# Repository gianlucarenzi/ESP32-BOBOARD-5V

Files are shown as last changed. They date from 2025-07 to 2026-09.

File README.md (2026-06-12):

# ESP32-BOBOARD-5V

**ESP32 NodeMCU 5V Tolerant Breakout Board per Monitoraggio Bus 6502**

## 🌐 Language / Lingua




---

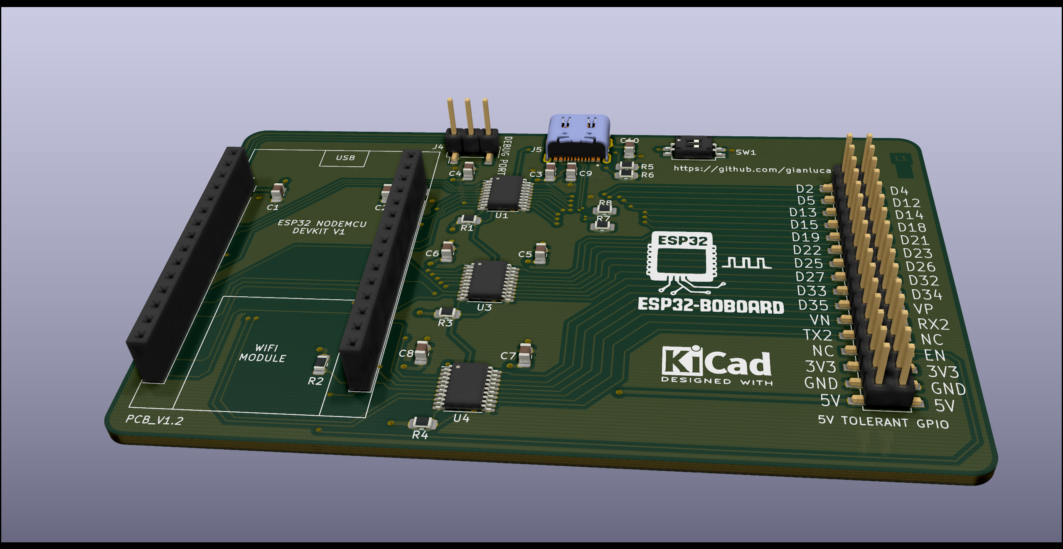
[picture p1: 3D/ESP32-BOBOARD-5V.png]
ESP32-BOBOARD-5V


## 📋 Indice

- [Panoramica del Progetto](#panoramica-del-progetto)
- [Caratteristiche Principali](#caratteristiche-principali)
- [Specifiche Tecniche](#specifiche-tecniche)
- [Visualizzazione 3D](#visualizzazione-3d)
- [Architettura Hardware](#architettura-hardware)
- [Firmware](#firmware)
- [Installazione e Setup](#installazione-e-setup)
- [Utilizzo](#utilizzo)
- [Diagrammi di Flusso](#diagrammi-di-flusso)
- [Tempistiche](#tempistiche)
- [File del Progetto](#file-del-progetto)
- [Produzione](#produzione)
- [Licenza](#licenza)
- [Contributi](#contributi)

## 🎯 Panoramica del Progetto

ESP32-BOBOARD-5V è una scheda breakout specializzata progettata per interfacciare un modulo ESP32 NodeMCU con sistemi basati su processore 6502, come l'Atari 8-bit. La scheda fornisce:

- **Tolleranza 5V** per tutti i pin GPIO
- **Monitoraggio del bus 6502** in tempo reale
- **Implementazione PBI (Parallel Bus Interface)** per Atari
- **Level shifting bidirezionale** per compatibilità 3.3V/5V
- **Connettori standard** per facile integrazione

### 🎮 Applicazioni Principali

- Monitoraggio e debug di sistemi 6502
- Implementazione di periferiche PBI per Atari
- Analisi del traffico del bus dati/indirizzi
- Emulazione di ROM e RAM esterne
- Sviluppo di cartucce intelligenti

## ✨ Caratteristiche Principali

### Hardware
- **ESP32 NodeMCU** compatibile (240MHz dual-core)
- **3x TXS0108E** level shifters bidirezionali
- **Tolleranza 5V** su tutti i pin GPIO
- **Connettore USB-C** per programmazione e alimentazione
- **Connettore PBI** standard per Atari
- **Pin header** per accesso completo ai GPIO
- **LED di stato** e pulsanti di controllo

### Firmware
- **PBI ROM Emulator** ($D800–$DFFF, 2 KB — decode completo A0-A10, nessun aliasing)
- **Dual-core processing** (Core 0: Serial/Log, Core 1: Monitor bus)
- **MPD** asserted durante accessi ROMSEL
- **EXTSEL** asserted durante accessi $D1XX con latch attivo
- **Latch interno** controllato via scrittura a $D1FF ($80 = enable, $00 = disable)
- **Coda FreeRTOS** (Core 1 → Core 0): log cambi stato latch VCS e ogni accesso $D100–$D1FE con timestamp in microsecondi

## 🔧 Specifiche Tecniche

| Parametro | Valore |
|---|---|
| **Microcontrollore** | ESP32-WROOM-32 |
| **Frequenza CPU** | 240 MHz (dual-core) |
| **Memoria Flash** | 4MB |
| **RAM** | 520KB |
| **GPIO disponibili** | 30 pin |
| **Level Shifters** | 3x TXS0108E (8-bit bidirezionali) |
| **Alimentazione** | 5V via USB-C o pin |
| **Logica I/O** | 3.3V/5V tolerant |
| **Dimensioni PCB** | 21.7mm x 21.7mm |
| **Layers** | 4 layer PCB |

### Pinout 6502 Bus

| Segnale | Pin ESP32 | Descrizione |
|---|---|---|
| **D0-D7** | GPIO4, GPIO5, GPIO13, GPIO14, GPIO16, GPIO17, GPIO18, GPIO19 | Data Bus (Bidirezionale) |
| **A0-A3** | GPIO34, GPIO35, GPIO36, GPIO39 | Address Bus LSB (Input Only) |
| **A4-A7** | GPIO32, GPIO33, GPIO21, GPIO27 | Address Bus |
| **A8-A10** | GPIO12, GPIO25, GPIO26 | Address Bus (decode completo 2 KB) |
| **PHI2** | GPIO2 | Clock 6502 (1.79 MHz) |
| **R/W** | GPIO15 | Read/Write |
| **SEL_N** | GPIO22 | Selezione $D1XX / CCTL (Active Low, Input) |
| **ROMSEL** | GPIO23 | Range $D800–$DFFF (Active Low, Input) |
| **EXTSEL** | GPIO3 (RX0) | Disabilita memoria interna Atari (Active Low, Output) |
| **MPD** | GPIO0 (BOOT) | Math Pack Disable (Active Low, Output) |

## 🎨 Visualizzazione 3D

### 📱 Viewer Online Interattivi

Visualizza i modelli 3D direttamente nel browser:







### 📥 Download File 3D

| Formato | Descrizione | Download |
|---|---|---|
| **STEP** | Modello CAD parametrico |  |
| **WRL** | Modello VRML per rendering |  |

### 🖼️ Galleria Immagini 3D

<table>
  <tr>
    <td align="center">
      Vista Isometrica
      <br/><b>Vista Isometrica</b>
    </td>
    <td align="center">
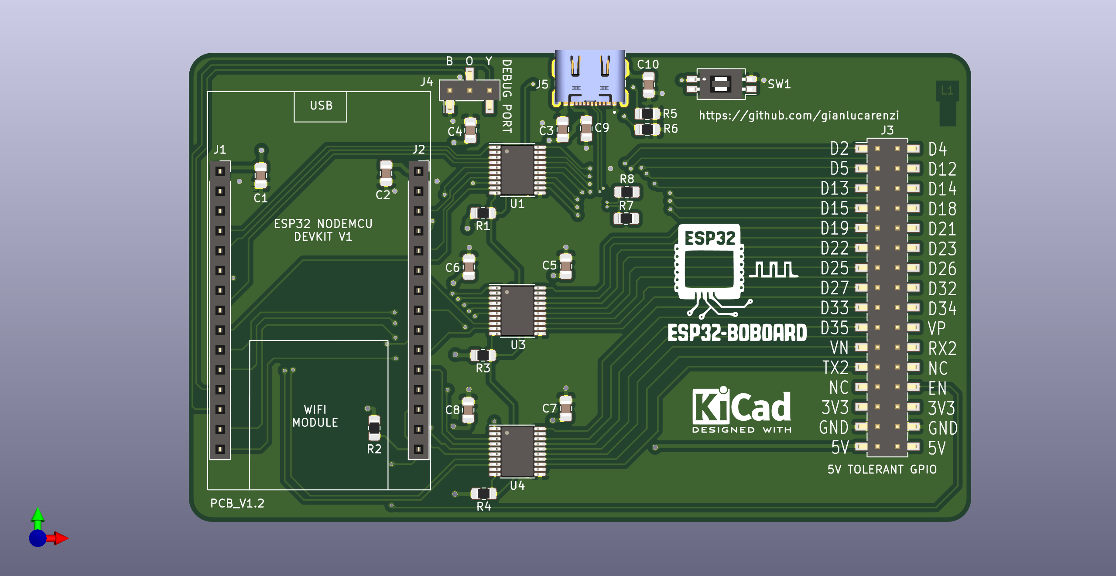
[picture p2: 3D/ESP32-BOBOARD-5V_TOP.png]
Vista Superiore
      
      <br/><b>Vista Superiore</b>
    </td>
  </tr>
  <tr>
    <td align="center">
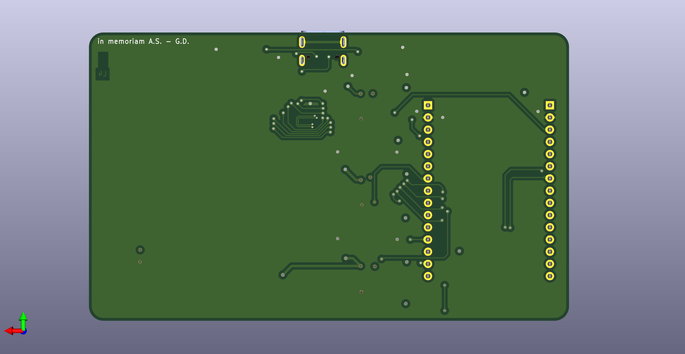
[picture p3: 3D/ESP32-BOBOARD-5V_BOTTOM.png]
Vista Inferiore
      
      <br/><b>Vista Inferiore</b>
    </td>
    <td align="center">
      Schema Elettrico
      <br/><b><a href="schematics/ESP32-BOBOARD-5V.pdf">📄 Schema Elettrico</a></b>
    </td>
  </tr>
</table>

### 🛠️ Software Consigliati per Visualizzazione

| Software | Formato | Piattaforma | Gratuito |
|---|---|---|---|
| **FreeCAD** | STEP, WRL | Windows, Linux, macOS | ✅ |
| **Fusion 360** | STEP | Windows, macOS | ✅ (Personal) |
| **Blender** | WRL | Windows, Linux, macOS | ✅ |
| **MeshLab** | WRL | Windows, Linux, macOS | ✅ |
| **CAD Exchanger Viewer** | STEP, WRL | Browser | ✅ |
| **3D Viewer Online** | STEP, WRL | Browser | ✅ |
| **Autodesk Viewer** | STEP | Browser | ✅ |

---

## 🏗️ Architettura Hardware

### Schema a Blocchi

```mermaid
flowchart TD
    A[ESP32 NodeMCU] --> B[TXS0108E #1]
    A --> C[TXS0108E #2] 
    A --> D[TXS0108E #3]
    
    B --> E[Data Bus D0-D7]
    C --> F[Address Bus A0-A7]
    D --> G[Address A8-A10 + Controls]
    
    E --> H[6502 System]
    F --> H
    G --> H
    
    I[USB-C] --> A
    J[Pin Headers] --> A
    K[PBI Connector] --> H
    
    style A fill:#e1f5fe
    style H fill:#f3e5f5
    style I fill:#e8f5e8
```

### Level Shifting

La scheda utilizza tre TXS0108E per garantire la compatibilità tra i livelli logici 3.3V dell'ESP32 e i 5V del sistema 6502:

- **TXS0108E #1**: Data Bus D0-D7 (bidirezionale)
- **TXS0108E #2**: Address Bus A0-A7
- **TXS0108E #3**: Address Bus A8-A10 + segnali di controllo (PHI2, R/W, SEL\_N, ROMSEL, EXTSEL, MPD)

## 💻 Firmware

### Architettura Software

Il firmware è basato su FreeRTOS e utilizza entrambi i core dell'ESP32:

- **Core 0**: Gestione comunicazione seriale e debug
- **Core 1**: Monitoraggio bus 6502 ad alta velocità

### Funzionalità Principali

#### 1. Monitoraggio Bus 6502
```cpp
// Lettura ottimizzata del bus indirizzi
static inline uint16_t read_address_bus(void) {
    uint32_t gpio_low = read_gpio_low();
    uint32_t gpio_high = read_gpio_high();
    // Combinazione bit per ricostruire indirizzo 16-bit
    return address_reconstruction;
}
```

#### 2. Implementazione PBI

| Range Indirizzi | Funzione | Note |
|---|---|---|
| **$D100–$D11F** | Registri VERA (accesso via EXTSEL) | Solo con latch attivo |
| **$D1FF** | Latch control (W: $80=on, $00=off) | Solo PBI mode |
| **$D800–$DFFF** | PBI ROM 2 KB — driver VERA X16 | A0-A10 decodificati, nessun aliasing |

#### 3. Sorgenti 6502 (ROM)

| File | Descrizione |
|---|---|
| `6502/src/vera_pbi_handler.s` | Driver PBI ROM per scheda VERA X16. Intestazione standard Earl Rice ($D800–$D81C), handler CIO, vettori OPEN/CLOSE/GET/PUT/STATUS/SPECIAL, init VERA. |
| `6502/src/vera_common.inc` | Simboli condivisi: indirizzi registri VERA (`VERA_ADDR_L/M/H`, `VERA_DATA0/1`, `VERA_CTRL`, …), costanti PBI (`PBI_ADDR=$D100`, `PBI_LATCH=$D1FF`), layout schermo. |
| `6502/pbi-driver.ld` | Linker script: segmento `ROM` origin `$D800`, size `$0800` (2 KB). |
| `include/pbi-driver.h` | Array C `pbi_driver[]` generato automaticamente dal Makefile — non modificare a mano. |

### Modalità di Funzionamento

#### Modalità PBI (Default)
```ini
-D BUS_MODE=0  ; BUS_MODE_PBI
```
- Emulazione dispositivo PBI Atari
- ROMSEL ($D800–$DFFF): assert MPD, serve byte ROM su letture (A0-A10)
- SEL_N ($D1XX): assert EXTSEL quando latch attivo
- Latch VCS: abilitato da `$80` a $D1FF, disabilitato da `$00`

#### Modalità CCTL (Cartridge)
```ini
-D BUS_MODE=1  ; BUS_MODE_CCTL
```
- Modalità Cartridge Control semplificata
- Latch sempre attivo (EXTSEL sempre asserted su $D1XX)
- Non gestisce $D1FF come controllo latch

## 🚀 Installazione e Setup

### Requisiti Hardware
- ESP32 NodeMCU (38 pin)
- Cavo USB-C per programmazione
- Sistema 6502 target (es. Atari 130XE)
- Connessioni bus secondo pinout

### Requisiti Software
- [PlatformIO](https://platformio.org/) o Arduino IDE
- ESP32 Arduino Core v2.0.14
- Driver USB-C per il sistema operativo

### Compilazione Firmware

1. **Clone del repository**:
```bash
git clone https://github.com/gianlucarenzi/esp32-boboard-5v.git
cd ESP32-BOBOARD-5V/firmware/6502_monitor
```

2. **Configurazione PlatformIO**:
```ini
[env:nodemcu-32s]
platform = espressif32
board = nodemcu-32s
framework = arduino
monitor_speed = 115200
board_build.f_cpu = 240000000
upload_speed = 921600
```

3. **Compilazione e upload**:
```bash
pio run --target upload
pio device monitor
```

### Configurazione Hardware

1. **Connessione ESP32**: Inserire il modulo NodeMCU nei socket
2. **Alimentazione**: Collegare USB-C o alimentazione 5V
3. **Bus 6502**: Collegare secondo il pinout specificato
4. **Test**: Eseguire modalità test per verifica connessioni

## 📊 Utilizzo

### Avvio Sistema

1. **Power-on**: Alimentare la scheda
2. **Monitor seriale**: Aprire terminale a 115200 baud
3. **Inizializzazione**: Attendere messaggio di ready
4. **Connessione 6502**: Collegare al sistema target

### Output Seriale

Il firmware stampa su Core 0 ogni evento loggato da Core 1 via coda FreeRTOS.
Il formato è `[secondi.microsecondi]`:

```
[6502_monitor] PBI ROM Emulator booting...
[6502_monitor] Running.
[6502_monitor] VCS=OFF  Latch=DISABLED
[    0.012345] [VCS ] Latch ENABLED  ($80 written to $D1FF)
[    0.012346] [D100 - VERA_ADDR_L          ] R $00
[    0.012390] [D103 - VERA_DATA0           ] W $FF
[    1.234567] [D104 - VERA_DATA1           ] W $00
[    1.234600] [VCS ] Latch DISABLED ($00 written to $D1FF)
```

- `[VCS ]` — cambio di stato del latch: `ENABLED` / `DISABLED`
- `[D1xx - NOME_REGISTRO]` — accesso a registro VERA con nome simbolico: `R` = lettura, `W` = scrittura
- I registri $09–$0C sono muxati da DCSEL: il logger traccia ogni scrittura a `VERA_CTRL` ($D105, bit [2:1]) per risolvere il nome corretto
- Il timestamp è catturato in Core 1 al momento del ciclo di bus (`esp_timer_get_time()`)
- Gli eventi persi quando la coda è piena vengono scartati senza bloccare il bus handler

## 📈 Diagrammi di Flusso

### Flusso Principale del Monitor

```mermaid
flowchart TD
    A[Avvio Sistema] --> B[Init GPIO + Drive LUT]
    B --> C[Crea coda FreeRTOS]
    C --> D[Avvia MonitorTask su Core 1]
    D --> E[Core 0: loop drain coda e Serial.printf]
    D --> F[Core 1: attesa PHI2 rising edge]

    F --> G[Campiona GPIO.in / GPIO.in1]
    G --> H[Decode indirizzo A0-A10 e R/W]
    H --> I{ROMSEL attivo?}

    I -->|Sì D800-DFFF| J[Assert MPD]
    J --> K{R/W = Read?}
    K -->|Sì| L[bus_drive pbi_rom addr]
    K -->|No| M[nessuna azione dati]

    I -->|No| N{SEL_N attivo?}
    N -->|Sì D1XX| O{latch attivo?}
    O -->|Sì| P[Assert EXTSEL]
    O -->|No| Q[EXTSEL rilasciato]
    P --> R{offset = $FF e Write?}
    Q --> R
    R -->|Sì PBI latch| S[Aggiorna latch, log EVT_LATCH se cambia]
    R -->|No D100-D1FE| T[log EVT_REG con R/W e dato]
    N -->|No| U[EXTSEL rilasciato]

    L --> V[Attesa PHI2 falling edge]
    M --> V
    S --> V
    T --> V
    U --> V
    V --> W[bus_release]
    W --> F

    style A fill:#e1f5fe
    style E fill:#f3e5f5
    style F fill:#e8f5e8
```

### Protocollo Latch VCS (PBI Mode)

```mermaid
sequenceDiagram
    participant CPU as 6502 CPU
    participant ESP as ESP32 MonitorTask
    participant Q  as FreeRTOS Queue

    CPU->>ESP: Write $80 → $D1FF
    ESP->>ESP: latch_active = true
    ESP->>ESP: Assert EXTSEL (LOW)
    ESP->>Q: EVT_LATCH ENABLED (timestamp µs)

    loop Accessi VERA $D100-$D1FE
        CPU->>ESP: Read/Write $D1xx
        ESP->>Q: EVT_REG offset data R/W (timestamp µs)
    end

    CPU->>ESP: Write $00 → $D1FF
    ESP->>ESP: latch_active = false
    ESP->>ESP: Release EXTSEL (HIGH)
    ESP->>Q: EVT_LATCH DISABLED (timestamp µs)
```

## ⏱️ Tempistiche

### Timing Critici

| Operazione | Tempo | Note |
|---|---|---|
| **PHI2 Period** | 1.77 MHz (PAL) / 1.79 MHz (NTSC) | Clock Atari 6502 |
| **Address Setup** | <100ns | Prima del rising edge PHI2 |
| **Data Setup** | <200ns | Per operazioni di write |
| **Data Hold** | <100ns | Dopo falling edge PHI2 |
| **GPIO Read** | ~125ns | Lettura registri ESP32 |
| **Level Shift** | <10ns | Propagazione TXS0108E |

### Diagramma Temporale Bus 6502

```mermaid
gantt
    title Timing Diagram - 6502 Bus Cycle
    dateFormat X
    axisFormat %L
    
    section PHI2
    High Phase    :active, phi2h, 0, 500
    Low Phase     :phi2l, 500, 1000
    
    section Address Bus
    Address Valid :addr, 0, 900
    Address Hold  :addrh, 900, 1000
    
    section Data Bus (Read)
    Data Setup    :data, 100, 400
    Data Valid    :active, datav, 400, 800
    Data Hold     :datah, 800, 900
    
    section R/W Signal
    Read Cycle    :active, rw, 0, 1000
```

### Performance del Monitor

- **Frequenza campionamento**: ~4 MHz (limitata da ESP32)
- **Latenza risposta**: <1μs per operazioni PBI
- **Throughput seriale**: 115200 baud per debug
- **Utilizzo CPU**: ~80% Core 1, ~20% Core 0
- **Compatibilità**: Atari PAL (1.77 MHz) e NTSC (1.79 MHz)

## 📁 File del Progetto

### Struttura Directory

```
ESP32-BOBOARD-5V/
├── 📁 firmware/
│   └── 📁 6502_monitor/
│       ├── 📄 platformio.ini          # Configurazione PlatformIO
│       ├── 📄 pre_build.py            # Script pre-build: assembla il ROM 6502
│       ├── 📁 src/
│       │   └── 📄 main.cpp            # Firmware ESP32 (PBI ROM emulator)
│       ├── 📁 include/
│       │   └── 📄 pbi-driver.h        # Array C generato dal ROM 6502 (auto)
│       └── 📁 6502/
│           ├── 📄 Makefile            # Assembla vera_pbi_handler.s → pbi-driver.h
│           ├── 📄 pbi-driver.ld       # Linker script (origin $D800, size 2 KB)
│           └── 📁 src/
│               ├── 📄 vera_pbi_handler.s  # PBI ROM driver per scheda VERA X16
│               └── 📄 vera_common.inc     # Simboli condivisi: registri VERA, costanti PBI
├── 📁 schematics/
│   └── 📄 ESP32-BOBOARD-5V.pdf    # Schema elettrico
├── 📁 3D/
│   ├── 🖼️ ESP32-BOBOARD-5V.png    # Render 3D
│   ├── 🖼️ ESP32-BOBOARD-5V_TOP.png
│   ├── 🖼️ ESP32-BOBOARD-5V_BOTTOM.png
│   └── 📄 ESP32-BOBOARD-5V.step   # Modello 3D
├── 📁 production/
│   ├── 📄 *.gbl, *.gtl           # File Gerber
│   ├── 📄 *.drl                  # File drill
│   └── 📄 ESP32BOBOARD-5V-1.0.zip
├── 📁 ibom/
│   └── 📄 ibom.html              # Interactive BOM
├── 📄 ESP32-BOBOARD-5V.kicad_pcb  # PCB KiCad
├── 📄 ESP32-BOBOARD-5V.sch        # Schema KiCad
├── 📄 ESP32-BOBOARD-5V.csv        # Bill of Materials
└── 📄 README.md                   # Questo file
```

### File di Produzione

#### Bill of Materials (BOM)

| Componente | Quantità | Package | LCSC Part |
|---|---|---|---|
| **TXS0108EPW** | 3 | TSSOP-20 | C17206 |
| **100µF Capacitor** | 9 | 0805 | C141660 |
| **100nF Capacitor** | 1 | 0805 | C840116 |
| **10kΩ Resistor** | 4 | 0805 | C84376 |
| **5.1kΩ Resistor** | 2 | 0805 | C27834 |
| **1% Precision Resistor** | 2 | 0805 | C328378 |
| **Pin Socket 1x15** | 2 | THT | - |
| **Pin Header 2x16** | 1 | SMD | C6332241 |
| **USB-C Connector** | 1 | SMD | C3197885 |
| **SPST Switch** | 1 | SMD | C319052 |

#### File Gerber
- **4-layer PCB** ottimizzato per segnali ad alta velocità
- **Impedenza controllata** per linee critiche
- **Ground planes** per riduzione EMI
- **Via stitching** per integrità del segnale

## 🏭 Produzione

### Specifiche PCB

| Parametro | Valore |
|---|---|
| **Layers** | 4 |
| **Thickness** | 1.6mm |
| **Min Track** | 0.1mm |
| **Min Via** | 0.2mm |
| **Copper Weight** | 1oz (35μm) |
| **Surface Finish** | HASL Lead-Free |
| **Solder Mask** | Green |
| **Silkscreen** | White |

### Assembly

1. **SMD Components**: Assemblaggio automatico raccomandato
2. **THT Components**: Saldatura manuale pin headers
3. **Test**: Verifica continuità e test funzionale
4. **Programming**: Upload firmware di test

## 📜 Licenza

Questo progetto è rilasciato sotto **GNU General Public License v3.0**.

```
ESP32-BOBOARD-5V - ESP32 NodeMCU 5V Tolerant Breakout Board
Copyright (C) 2024 RetroBitLab

This program is free software: you can redistribute it and/or modify
it under the terms of the GNU General Public License as published by
the Free Software Foundation, either version 3 of the License, or
(at your option) any later version.
```

Vedi il file [LICENSE](LICENSE) per i dettagli completi.

## 🤝 Contributi

I contributi sono benvenuti! Per contribuire:

1. **Fork** del repository
2. **Crea** un branch per la tua feature (`git checkout -b feature/AmazingFeature`)
3. **Commit** delle modifiche (`git commit -m 'Add some AmazingFeature'`)
4. **Push** al branch (`git push origin feature/AmazingFeature`)
5. **Apri** una Pull Request

### Aree di Contributo

- 🐛 **Bug fixes** e miglioramenti firmware
- 📚 **Documentazione** e tutorial
- 🔧 **Hardware** ottimizzazioni e varianti
- 🧪 **Testing** e validazione
- 🎨 **Examples** e progetti dimostrativi

### Reporting Issues

Per segnalare problemi, utilizzare il sistema di [Issues](../../issues) includendo:
- Descrizione dettagliata del problema
- Versione hardware e firmware
- Log seriali se disponibili
- Passi per riprodurre il problema

---

## 📞 Contatti

- **Progetto**: ESP32-BOBOARD-5V
- **Autore**: RetroBitLab
Repository: [GitHub](https://github.com/gianlucarenzi/esp32-boboard-5v)
- **Documentazione**: [Wiki](../../wiki)

---

*Realizzato con ❤️ per la comunità retro-computing*

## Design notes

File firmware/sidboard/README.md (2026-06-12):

# Sidboard — ESP32 CCTL/SID Firmware for Atari 8-bit

Firmware for an **ESP32 (NodeMCU-32S)** expansion board connected to an Atari 8-bit computer via the **CCTL (Cartridge Control Line)**. It provides:

- **SID 6581/8580 sound emulation** (3 square-wave voices, 22050 Hz, via ESP32 DAC1 on GPIO 25)
- **Real-time bus monitoring** synchronized to the 6502 PHI2 clock
- **Timestamped serial log** of every register access and latch event
- **Zero FreeRTOS overhead** in the hot bus-sampling path

---

## Table of Contents

1. [Hardware Requirements](#hardware-requirements)
2. [Pin Mapping](#pin-mapping)
3. [Memory Map](#memory-map)
4. [Architecture](#architecture)
5. [SID Register Map](#sid-register-map)
6. [cSIDLight Audio Engine](#csidlight-audio-engine)
7. [Audio Circuit](#audio-circuit)
8. [Build and Flash](#build-and-flash)
9. [Usage from Atari Side](#usage-from-atari-side)
10. [File Structure](#file-structure)

---

## Hardware Requirements

| Component | Detail |
|---|---|
| MCU | ESP32 (NodeMCU-32S) @ 240 MHz |
| Atari interface | Cartridge slot — CCTL line ($D5xx), 5-bit address bus, 8-bit data bus |
| Level translator | TXS0108 — 3.3 V ↔ 5 V for data and address lines |
| Audio output | GPIO 25 (DAC1) → audio mixer via RC filter |

---

## Pin Mapping

> Full detail including free GPIOs and physical layout: see **[PIN_MAPPING.md](PIN_MAPPING.md)**.

### Control Signals

| Signal | GPIO | Direction | Description |
|---|---|---|---|
| PHI2 | 2 | Input | 6502 phase-2 clock (1.79 MHz PAL); rising edge triggers bus sample |
| R/W | 15 | Input | High = Read, Low = Write |
| SEL_N | 22 | Input, Active Low | CCTL — asserted by Atari for $D5xx page accesses |

### Data Bus (bidirectional)

| Bit | GPIO |
|-----|---|
| D0 | 4 |
| D1 | 5 |
| D2 | 13 |
| D3 | 14 |
| D4 | 16 |
| D5 | 17 |
| D6 | 18 |
| D7 | 19 |

### Address Bus (input only, A0–A4)

| Bit | GPIO | GPIO_IN1 bit |
|-----|---|---|
| A0 | 34 | bit 2 |
| A1 | 35 | bit 3 |
| A2 | 36 | bit 4 |
| A3 | 39 | bit 7 |
| A4 | 32 | bit 0 |

Only 5 address bits are decoded (32 locations). A5–A10 are not wired.

### Audio and Debug

| Signal | GPIO | Direction | Description |
|---|---|---|---|
| DAC1 | 25 | Output | SID audio — 8-bit, 22050 Hz, mono |
| TX | 1 | Output | Serial debug, 115200 baud, TX-only |

---

## Memory Map

```
CCTL active ($D5xx, SEL_N low) — A0-A4 decoded to 5-bit offset:

Offset   Full address   Description
──────   ────────────   ──────────────────────────────────────────────────
0x00     $D500          SID register 0  (V1 Freq Lo)
 …        …              …
0x1E     $D51E          SID register 30 (unused)
0x1F     $D5FF *        Latch control — bit 0: 1=enable, 0=disable+reset
```

\* $D5FF is decoded as offset 0x1F because only A0–A4 are wired (all five bits high).  
SID registers are accessible for reads and writes only when the latch is enabled.

---

## Architecture

### Dual-Core Split

```
Core 0 (system)                  Core 1 (dedicated)
────────────────                 ─────────────────────────────────────────
loop()                           MonitorTask  (priority 10, IRAM)
 ├─ sidLight->process()           ├─ PHI2 rising-edge sync (tight polling)
 ├─ drain latchEventQueue         ├─ SEL_N (CCTL) detection
 └─ drain log_queue → Serial      ├─ A0-A4 address decode
                                  ├─ Data bus drive (read cycle)
esp_timer @ 22050 Hz             └─ Data bus sample (write cycle)
 └─ cSIDLight::_tick()
    └─ dacWrite(GPIO 25)
```

**Core 1** owns the entire bus timing path. No FreeRTOS primitives are called inside the hot loop — the only inter-core communication is two non-blocking `xQueueSend(..., 0)` calls: one for latch state changes, one for the log queue.

**Cross-core shared state** (`_regs[]`) is declared `volatile uint8_t`. On Xtensa LX6, DRAM is not cached per-core, so volatile byte stores from Core 1 are immediately visible to Core 0 without explicit barriers.

**Log drain** dequeues at most **one entry per `loop()` iteration**. `Serial.printf()` at 115200 baud blocks ~3.5 ms per line; draining all 64 entries in a tight loop would stall `sidLight->process()` for ~220 ms, delaying SID register propagation to the audio engine. The 64-entry queue absorbs bursts while `process()` runs at full loop rate.

### MonitorTask Flow (Core 1)

```
for (;;) {
    wait PHI2 rising edge          ← tight polling loop, no interrupt latency
    if SEL_N not asserted → continue

    decode A0-A4 from GPIO_IN1     ← 5-bit offset (0x00-0x1F)

    if R/W == Read:
        if latch enabled and offset < 0x1F:
            drive data bus from sidLight->read(offset)
        wait PHI2 falling edge
        release data bus (High-Z)

    if R/W == Write:
        wait PHI2 falling edge     ← data stable on falling edge
        sample data bus
        if offset == 0x1F:         → update latch, notify Core 0
        else if latch enabled:     → sidLight->write(offset, data)
}
```

### Data Bus LUT

`data_set_lut[256]` is precomputed at boot in IRAM: each entry holds the GPIO bitmask for the 8 data pins corresponding to a given byte value. Driving the bus on a read is an O(1) indexed bitmask lookup with no bit-scatter at runtime.

---

## SID Register Map

Registers are accessible at `$D500` (offset `0x00`) through `$D51E` (offset `0x1E`).  
Offset `0x1F` ($D5FF) is the latch control register, not a SID register.

| Offset | Address | Register | Description |
|---|---|---|---|
| `$00/$01` | `$D500/$D501` | V1 Freq Lo/Hi | Voice 1 frequency (16-bit) |
| `$02/$03` | `$D502/$D503` | V1 PW Lo/Hi | Voice 1 pulse width (not emulated) |
| `$04` | `$D504` | V1 CTRL | bit 0 = GATE, bit 6 = SQR wave |
| `$05/$06` | `$D505/$D506` | V1 AD/SR | Voice 1 ADSR (not emulated) |
| `$07–$0D` | `$D507–$D50D` | V2 | Voice 2 (same layout as V1) |
| `$0E–$14` | `$D50E–$D514` | V3 | Voice 3 (same layout as V1) |
| `$15/$16` | `$D515/$D516` | FC Lo/Hi | Filter cutoff (not emulated) |
| `$17` | `$D517` | Res/Filt | Filter resonance / routing (not emulated) |
| `$18` | `$D518` | MODE/VOL | Bits 3:0 = master volume (0–15) |
| `$19/$1A` | `$D519/$D51A` | OSC3/ENV3 | Voice 3 readouts |
| `$1B–$1E` | `$D51B–$D51E` | — | Unused |
| **`$1F`** | **`$D5FF`** | **LATCH** | **bit 0: 1=enable SID, 0=disable+reset** |

---

## cSIDLight Audio Engine

Defined in `include/csidlight.h`. Self-contained — no external audio library.

### Parameters

| Parameter | Value |
|---|---|
| Target sample rate | 22050 Hz |
| Timer period | 45 µs (`SID_TIMER_US`, integer truncation of 45.351 µs) |
| Actual sample rate | 22222 Hz (`SID_ACTUAL_RATE = 1000000 / SID_TIMER_US`) |
| Output pin | GPIO 25 (ESP32 DAC1) |
| Voices | 3 independent square-wave oscillators |
| Emulated | Frequency, GATE, master volume |
| Not emulated | ADSR envelope, waveform selection, filter, ring-mod, sync |

### Frequency Formula (PAL clock = 985248 Hz)

`esp_timer` fires every 45 µs (integer microseconds), giving an actual sample rate of 22222 Hz rather than the nominal 22050 Hz. `_phaseIncFor()` uses `SID_ACTUAL_RATE` to match the real timer cadence and keep pitch accurate.

```
freq_hz  = (reg16 × 985248) / 2^24
phaseInc = (freq_hz × 2^32) / 22222     ← SID_ACTUAL_RATE, not 22050
```

At each tick the oscillator phase always advances, regardless of gate state (as on a real SID):

```
phase[i] += phaseInc[i]                 ← unconditional
if voiceVol[i] != 0:
    square = (phase[i] & 0x80000000) ? +voiceVol[i] : -voiceVol[i]
    mix   += square
mix = clamp(128 + mix, 0, 255)
dacWrite(25, mix)
```

### Master Volume

Volume nibble is multiplied before dividing to avoid integer truncation loss:

```
voiceVol = (reg[$18] & 0x0F) × 128 / 48   // max 40 per voice; 3 × 40 = 120 ≤ 128
```

### API Surface

| Method | Caller | Description |
|---|---|---|
| `write(reg, val)` | MonitorTask (Core 1, IRAM) | Single `volatile` byte store — no locking |
| `read(reg)` | MonitorTask (Core 1, IRAM) | Single `volatile` byte load |
| `process()` | `loop()` (Core 0) | Snapshot diff → update synthesis params |
| `reset()` | `loop()` on latch disable | Zero all registers, silence voices |
| `_tick()` | `esp_timer` (Core 0) | Generate one audio sample, write DAC |

---

## Audio Circuit

GPIO 25 is the ESP32 DAC1 output (0–3.3 V, 8-bit resolution, 22050 Hz).

**Signal path to audio mixer:**

```
GPIO 25 (DAC1)
    │
   10 µF  ──── DC block capacitor
    │
  100 kΩ  ──── audio input / POKEY ECI AUDIO IN
                │
               10 nF ─── GND      (low-pass, fc ≈ 1.75 kHz)
```

If connected to POKEY ECI AUDIO IN, the SID signal mixes directly into the POKEY audio mixer and appears on the Atari speaker output together with POKEY audio.

---

## Build and Flash

### Prerequisites

- [PlatformIO](https://platformio.org/) (CLI or IDE plugin)
- ESP32 platform: `espressif32 @ 6.6.0`

### Environments

Two build environments are defined in `platformio.ini`:

| Environment | Description |
|---|---|
| `nodemcu-32s` | Normal firmware — Atari bus monitor + cSIDLight |
| `nodemcu-32s-demo` | Demo mode (`-D AUDIO_DEMO`) — plays `Commando_dmp.h` at 50 Hz, no Atari required |

### Build

```bash
# Normal (Atari bus monitor)
pio run -e nodemcu-32s

# Demo (standalone SID playback)
pio run -e nodemcu-32s-demo
```

### Flash

```bash
pio run -e nodemcu-32s -t upload
# or
pio run -e nodemcu-32s-demo -t upload
```

Default upload speed: 921600 baud. Adjust `upload_port` in `platformio.ini` if needed.

### Monitor

```bash
pio device monitor -b 115200
```

Serial output is TX-only on GPIO 1. Example log output (normal mode):

```
[sidboard] CCTL/SID Firmware Ready (TX-Only)
[sidboard] cSIDLight initialized, DAC1 on GPIO 25
[sidboard] MonitorTask running on Core 1.
>>> Latch ENABLED
[    0.123456] [LATCH] $D5FF ENABLED  ($01)
[    0.123500] [D500 - V1_FREQ_LO  ] W $3C
[    0.123501] [D504 - V1_CTRL     ] W $11
```

Demo mode startup:

```
[sidboard] CCTL/SID Firmware Ready (TX-Only)
[sidboard] cSIDLight initialized, DAC1 on GPIO 25
[sidboard] AUDIO_DEMO: Commando, 1100 frames @ 50 Hz (22.0 s, looping)
[sidboard] MonitorTask running on Core 1.
```

### Build Flags

| Flag | Purpose |
|---|---|
| `-O3` | Maximum optimization |
| `-Wno-shift-count-overflow` | Suppress benign GPIO bitmask shift warnings |
| `-D USE_ESP32_REGISTER_ACCESS` | Enable direct `GPIO.out_w1ts` / `GPIO.in` register access |
| `-D AUDIO_DEMO` | Enable standalone SID demo player (demo environment only) |

### AUDIO_DEMO Mode

When built with `-D AUDIO_DEMO`, the firmware loads a pre-captured SID register dump (`examples/Commando_dmp.h`) and replays it at **50 Hz** (PAL VBlank rate) via a dedicated `esp_timer`, writing all 25 SID registers to `cSIDLight` each frame.

The dump format is a flat `uint8_t` array: `N_frames × 25 bytes`, registers `0x00–0x18` per frame. At frame end the player loops.

To use a different tune, replace `Commando_dmp.h` with any SID register dump in the same format (generated by `sidplayfp` + a custom capture tool, or equivalent) and update the `#include` in `main.cpp`.

---

## Usage from Atari Side

SID registers are directly accessible via POKE/PEEK in the $D5xx range. The latch must be enabled first.

### Enable the SID

Write `$01` to `$D5FF` ($54783):

```
POKE 54783, 1   ; $D5FF — enable SID
```

### Disable the SID

```
POKE 54783, 0   ; $D5FF — disable and silence SID
```

### Write a SID Register (Atari BASIC)

```basic
POKE 54783, 1        : REM enable SID
POKE 54528, 100      : REM $D500 — V1 Freq Lo = 100
POKE 54529, 10       : REM $D501 — V1 Freq Hi = 10
POKE 54532, 17       : REM $D504 — V1 CTRL: GATE on + SQR wave ($11)
POKE 54552, 15       : REM $D518 — MODE/VOL: max volume
```

### Read a SID Register (Atari BASIC)

```basic
POKE 54783, 1
X = PEEK(54532)      : REM read V1 CTRL ($D504)
```

### Write a SID Register (cc65 C)

```c
#define SID_BASE  0xD500
#define SID_LATCH 0xD5FF

/* enable */
*(volatile uint8_t *)SID_LATCH = 0x01;

/* set voice 1 frequency and gate */
*(volatile uint8_t *)(SID_BASE + 0x00) = 0x3C;  /* Freq Lo */
*(volatile uint8_t *)(SID_BASE + 0x01) = 0x0A;  /* Freq Hi */
*(volatile uint8_t *)(SID_BASE + 0x04) = 0x11;  /* CTRL: GATE + SQR */
*(volatile uint8_t *)(SID_BASE + 0x18) = 0x0F;  /* MODE/VOL: max */
```

---

## File Structure

```
sidboard/
├── platformio.ini              Build configuration (ESP32, 240 MHz, -O3)
├── PIN_MAPPING.md              Full ESP32 ↔ Atari bus pin assignment table
├── Logs.md                     Architecture decisions and change log
├── README.md                   This file
├── src/
│   └── main.cpp               MonitorTask, setup(), loop(), LUT, GPIO config
├── include/
│   └── csidlight.h            cSIDLight class — audio engine (header-only)
├── 6502/
│   ├── src/pbi-driver.s       Legacy 6502 CIO device handler (not loaded)
│   ├── pbi-driver.ld          Linker script
│   └── Makefile               Builds pbi-driver.h from assembly
└── examples/
    ├── Commando_dmp.h             SID register dump — Commando (27500 bytes, 1100 frames @ 50 Hz)
    ├── cc65/
    │   ├── sid_dump_player.c   SID dump player (direct POKE, adapt for $D5xx)
    │   └── Makefile
    └── atari-basic/
        └── sid_dump_player.bas BASIC SID dump player (adapt for $D5xx)
```

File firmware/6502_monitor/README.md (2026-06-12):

# Atari PBI ROM Emulator & VERA Bus Monitor

High-performance ESP32-based firmware that emulates the Atari 8-bit Parallel Bus Interface (PBI) ROM slot ($D800-$DFFF) and logs VERA video-card register accesses via a FreeRTOS queue.

## Features
- **Bus Modes:**
    - **PBI Mode (Default):** Full Atari PBI device emulation. Serves a 2 KB ROM at $D800-$DFFF (A0-A10, no aliasing). Asserts MPD on ROMSEL; asserts EXTSEL when the PBI latch is active. Latch enabled by writing $80 to $D1FF, disabled by writing $00.
    - **CCTL Mode:** Cartridge Control mode. VCS latch always active; MPD, EXTSEL, and latch control ($D1FF) are not used.
- **VERA Register Logging:** Every access to $D100-$D1FE is captured by Core 1 and forwarded via a 64-entry FreeRTOS queue to Core 0 for Serial output. Each event carries a microsecond-precision timestamp (`esp_timer_get_time()`).
- **Serial Output Format:**
    ```
    [    0.001234] [VCS ] Latch ENABLED  ($80 written to $D1FF)
    [    0.002345] [D103 - VERA_DATA0           ] R $FF
    [    0.002346] [D105 - VERA_CTRL            ] W $04
    [    0.002347] [D109 - VERA_FX_CTRL         ] W $20
    ```
  Registers $09-$0C are muxed by DCSEL (bits `[2:1]` of `VERA_CTRL`); the logger tracks the last write to `$D105` to resolve the correct name automatically.
- **Fast Response:** IRAM-resident `MonitorTask` on Core 1 with direct GPIO register access (`GPIO.in`, `GPIO.out_w1ts/c`) for < 50 ns bus latency.
- **Hardware Target:** NodeMCU DevKit V1 (ESP32-WROOM).

## 6502 ROM Build Pipeline

The PBI ROM served at $D800-$DFFF is a real 2 KB 6502 binary assembled before the ESP32 build:

| Path | Description |
|---|---|
| `6502/src/vera_pbi_handler.s` | PBI ROM source: Atari header, INIT routine, VERA text-mode boot screen |
| `6502/src/vera_common.inc` | Shared VERA register definitions and screen-layout constants |
| `6502/pbi-driver.ld` | Linker script: places CODE/RODATA at $D800, size 2 KB |
| `6502/Makefile` | Assembles with `ca65`, links with `ld65`, emits `pbi-driver.h` via `hexdump` |
| `pre_build.py` | PlatformIO `pre:` hook — runs `make -C 6502/` before any C++ source is compiled |
| `include/pbi-driver.h` | Auto-generated C header: `IRAM_ATTR uint8_t pbi_driver[2048]` |

**Toolchain requirement:** `cc65` suite (`ca65`, `ld65`) must be on `$PATH`.

Build flow:
```
PlatformIO build → pre_build.py → make -C 6502/ → ca65 → ld65 → hexdump → pbi-driver.h
                                                                                  ↓
                                                              ESP32 C++ build includes it
```

The ROM INIT routine:
1. Registers the device in `PDVMSK` and sets `CRITIC = 0`.
2. Probes for VERA hardware readiness (`WAIT_VERA`).
3. Configures VERA Layer 1 in 128×64-cell tilemap mode (80 visible columns, 1:1 VGA scale).
4. Loads a compact 27-glyph boot font into VRAM at $1F000.
5. Clears the screen and prints a version line (VERA firmware revision from `DC_HSCALE`/`DC_VSCALE`/`DC_BORDER`) and a host-type line (ATARI XL / ATARI XE detected via `PORTB` bank-switching probe).

## Hardware Setup
Refer to the following documents for detailed pinout:
- [General Pin Mapping](PIN_MAPPING.md) (NodeMCU DevKit V1)
- [Hardware Architecture](HARDWARE.md)

## Development
This project uses **PlatformIO**.
- Style: **Allman** (braces on new line).
- Column Limit: **80**.
- Tool: `clang-format`.

### Configuration
Two build environments are defined in `platformio.ini`:

| Environment | `BUS_MODE` | Description |
|---|---|---|
| `nodemcu-32s` | `BUS_MODE_PBI` (0) | Default — full PBI emulation |
| `nodemcu-32s-cctl` | `BUS_MODE_CCTL` (1) | Cartridge Control mode |

Build and flash:
```sh
pio run -e nodemcu-32s --target upload        # PBI mode
pio run -e nodemcu-32s-cctl --target upload   # CCTL mode
```

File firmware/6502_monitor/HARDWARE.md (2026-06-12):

# VeraX16 PBI — Hardware Reference

## 1. Overview

The ESP32 interfaces the Atari 800XL/130XE PBI (Parallel Bus Interface) to:

- serve a 2 KB ROM image at **$D800–$DFFF** (A0-A10 fully decoded, no aliasing)
- respond to register reads/writes at **$D100–$D1FF** ($D1XX page)
- log every VERA register access (**$D100–$D1FE**) with microsecond timestamps via FreeRTOS queue
- assert **EXTSEL** to disable Atari internal memory when the PBI latch is active
- assert **MPD** (Math Pack Disable) whenever the ROMSEL window is selected

All 5 V Atari signals pass through **TXS0108E** bidirectional level translators
before reaching the 3.3 V ESP32 GPIOs.  The $D800–$DFFF chip-select is
generated in hardware by a **74HC138** 3-to-8 decoder.

---

## 2. Atari 6502 Bus Timing

### Clock source

| Parameter | Value |
|---|---|
| NTSC colour crystal | 14.31818 MHz |
| CPU (SALLY) clock | 14.31818 ÷ 8 = **1.7897 MHz** |
| Full bus cycle | ≈ **558.7 ns** |
| PHI2 HIGH period | ≈ **279 ns** |
| PHI2 LOW period | ≈ **279 ns** |

### Key 6502 timing parameters (65C02 / SALLY, worst-case)

| Parameter | Symbol | Value | Notes |
|---|---|---|---|
| Address valid after PHI2↓ | tADS | ≤ 300 ns | Address bus stable early in PHI2-LOW |
| Address hold after PHI2↓ | tAH | ≥ 10 ns | |
| **Read data setup before PHI2↓** | **tDSR** | **≥ 100 ns** | **Critical — ROM must drive bus in time** |
| Read data hold after PHI2↓ | tDHR | ≥ 10 ns | |
| Write data valid after PHI2↑ | tMDS | ≤ 225 ns (typ. 80–100 ns) | CPU drives data ~80 ns after PHI2↑ |
| Write data hold after PHI2↓ | tDHW | ≥ 10 ns | |

### Read cycle window

```
         PHI2
          ___________
_________|           |___________
         ^           ^
         PHI2↑       PHI2↓
         |           |
         |<- 279 ns ->|
```

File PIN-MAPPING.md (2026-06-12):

# ESP32-BOBOARD-5V — Pin Mapping

**Hardware**: ESP32-BOBOARD-5V (NodeMCU-32S + 3× TXS0108EPW level shifters)  
**Atari target**: 800XL PBI / 65XE-130XE ECI+CART  
**MCU**: ESP32-WROOM (3.3 V)

---

## GPIO Assignment (Firmware)

| Segnale | GPIO ESP32 | Etichetta Board | Dir | Descrizione |
| :--- | :---: | :--- | :---: | :--- |
| **D0** |  4 | D4 | I/O | Bus Dati bit 0 |
| **D1** |  5 | D5 | I/O | Bus Dati bit 1 |
| **D2** | 13 | D13 | I/O | Bus Dati bit 2 |
| **D3** | 14 | D14 | I/O | Bus Dati bit 3 |
| **D4** | 16 | RX2 | I/O | Bus Dati bit 4 |
| **D5** | 17 | TX2 | I/O | Bus Dati bit 5 |
| **D6** | 18 | D18 | I/O | Bus Dati bit 6 |
| **D7** | 19 | D19 | I/O | Bus Dati bit 7 |
| **A0** | 34 | D34 | IN  | Bus Indirizzi bit 0 (**Input Only**) |
| **A1** | 35 | D35 | IN  | Bus Indirizzi bit 1 (**Input Only**) |
| **A2** | 36 | VP | IN  | Bus Indirizzi bit 2 (**Input Only**) |
| **A3** | 39 | VN | IN  | Bus Indirizzi bit 3 (**Input Only**) |
| **A4** | 32 | D32 | IN  | Bus Indirizzi bit 4 |
| **A5** | 33 | D33 | IN  | Bus Indirizzi bit 5 |
| **A6** | 21 | D21 | IN  | Bus Indirizzi bit 6 |
| **A7** | 27 | D27 | IN  | Bus Indirizzi bit 7 |
| **A8** | 12 | D12 | IN  | Bus Indirizzi bit 8 |
| **A9** | 25 | D25 | IN  | Bus Indirizzi bit 9 |
| **A10**| 26 | D26 | IN  | Bus Indirizzi bit 10 |
| **PHI2** |  2 | D2 | IN  | Clock 6502 (1.79 MHz) |
| **R/W** | 15 | D15 | IN  | Read/Write |
| **SEL\_N** | 22 | D22 | IN  | Selezione $D1XX / CCTL (Active Low) |
| **ROMSEL** | 23 | D23 | IN  | Range $D800–$DFFF (Active Low) |
| **EXTSEL** |  3 | **RX0**  | OUT | Disabilita memoria interna Atari (Active Low) |
| **MPD** |  0 | **BOOT** | OUT | Math Pack Disable (Active Low) |
| **TX debug** | 1 | TX0 | OUT | Console seriale (115200 bps) |

---

## Note Tecniche

- **A0–A10 decodificati**: 11 bit di indirizzo coprono l'intero range $D800–$DFFF (2 KB) senza aliasing.
- **GPIO 0 (MPD/BOOT)**: il pull-up interno dell'Atari (isolato dal TXS0108E) mantiene GPIO 0 alto durante il boot dell'ESP32.
- **GPIO 3 (EXTSEL/RX0)**: condiviso con il pin RX della UART; non utilizzabile per input seriale durante l'esecuzione.
- **Bus Dati (LUT)**: GPIO non contigui → LUT da 256 entry precalcolata per scrivere sul bus alla massima velocità.
- **Bus Indirizzi A0–A5**: nel registro `GPIO_IN1_REG` (GPIO 32–39), lettura atomica in un ciclo.
- **Bus Indirizzi A6–A10**: nel registro `GPIO_IN_REG` (GPIO 0–31), campionati insieme agli altri segnali di controllo.
- Tutti i segnali Atari↔ESP32 passano attraverso i **TXS0108EPW** (3.3 V / 5 V).

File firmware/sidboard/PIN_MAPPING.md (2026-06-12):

# Sidboard — ESP32 Pin Mapping

Target board: **NodeMCU-32S** (ESP32-WROOM-32, 38 pin)

---

## Atari Bus Interface

### Data Bus (bidirectional)

| GPIO | NodeMCU | Direction | Atari signal | Note |
|---|---|---|---|---|
| 4 | D2 | In/Out | D0 | Data bit 0 |
| 5 | D1 | In/Out | D1 | Data bit 1 |
| 13 | D7 | In/Out | D2 | Data bit 2 |
| 14 | D5 | In/Out | D3 | Data bit 3 |
| 16 | RX2 | In/Out | D4 | Data bit 4 |
| 17 | TX2 | In/Out | D5 | Data bit 5 |
| 18 | D5/SCK  | In/Out | D6 | Data bit 6 |
| 19 | D6/MISO | In/Out | D7 | Data bit 7 |

### Address Bus (input only)

| GPIO | NodeMCU | Direction | Atari signal | GPIO_IN register |
|---|---|---|---|---|
| 34 | — | Input | A0 | GPIO_IN1 bit 2  |
| 35 | — | Input | A1 | GPIO_IN1 bit 3  |
| 36 | — | Input | A2 | GPIO_IN1 bit 4  |
| 39 | — | Input | A3 | GPIO_IN1 bit 7  |
| 32 | — | Input | A4 | GPIO_IN1 bit 0  |

> GPIOs 32–39 are read via `GPIO_IN1_REG` (upper bank). GPIOs 34–39 are input-only (no internal pull-up/down).

### Control Signals

| GPIO | NodeMCU | Direction | Signal  | Description |
|---|---|---|---|---|
| 2 | D4 | Input | PHI2 | 6502 Phase 2 clock — 1.79 MHz PAL; rising edge triggers bus sample |
| 15 | D8 | Input | R/W | Read/Write — High = Read, Low = Write |
| 22 | D6/SCL  | Input | SEL_N | CCTL active-low select — asserted for $D5xx page |

### Audio Output

| GPIO | NodeMCU | Direction | Signal | Description |
|---|---|---|---|---|
| 25 | — | Output | DAC1 | SID audio — 8-bit, 22050 Hz, mono; feed via RC filter to audio mixer |

---

## Address Decode Logic

Only A0–A4 are wired (5 bits → 32 locations):

```
SEL_N LOW  → CCTL active ($D5xx page)
offset 0x00–0x1E  →  SID registers  ($D500–$D51E)
offset 0x1F       →  Latch control   ($D5FF, A0–A4 all high)
```

Latch control byte: `bit 0 = 1` → enable SID; `bit 0 = 0` → disable + silence.

---

## Serial Debug

| GPIO | NodeMCU | Direction | Signal | Description |
|---|---|---|---|---|
| 1 | TX0 | Output | TX | UART0 TX — 115200 baud, TX-only mode |

> RX (GPIO 3) is not used. Serial is initialised with `Serial.begin(115200, SERIAL_8N1, -1, 1)` to keep GPIO 3 free.

---

## Free GPIOs

Pins available for future use:

| GPIO | NodeMCU | Capability | Former use |
|---|---|---|---|
| 0 | D3 | Output / Boot strap | — (boot pull-up required) |
| 3 | RX0 | Input / UART0 RX | — |
| 12 | D6 | Input / ADC2_CH5 / Touch5 | A8 (address bus) |
| 21 | D6/SDA  | In/Out / I²C SDA | A6 (address bus) |
| 23 | D7/MOSI | In/Out / SPI MOSI | ROMSEL |
| 26 | — | Output / **DAC2** | A10 (address bus) |
| 27 | — | In/Out / ADC2_CH7 / Touch7 | A7 (address bus) |
| 33 | — | Input / ADC1_CH5 / Touch8 | A5 (address bus) |

> **GPIO 26** is ESP32 DAC2 — available as a second audio channel or CV output.

---

## Reserved / Not Available

| GPIO | Reason |
|---|---|
| 6–11 | Internal SPI flash — hardwired, do not use |
| 34–39 | Input-only (no output drive, no pull-up/down) |

---

## NodeMCU-32S Physical Layout

Pin order follows the standard NodeMCU-32S 38-pin silk-screen (left column top→bottom, then right column top→bottom).

```
                      ┌────────────────────┐
              3V3  ───┤  1              38 ├───  GND
               EN  ───┤  2              37 ├───  GPIO23   free (was ROMSEL)
           GPIO39  ───┤  3  A3          36 ├───  GPIO22   SEL_N (CCTL)
           GPIO36  ───┤  4  A2          35 ├───  GPIO1    TX debug
           GPIO35  ───┤  5  A1          34 ├───  GPIO3    free
           GPIO34  ───┤  6  A0          33 ├───  GPIO21   free (was A6)
              GND  ───┤  7              32 ├───  GPIO19   D7
           GPIO32  ───┤  8  A4          31 ├───  GPIO18   D6
           GPIO33  ───┤  9  free(wasA5) 30 ├───  GPIO5    D1
           GPIO27  ───┤ 10  free(wasA7) 29 ├───  GPIO17   D5
           GPIO12  ───┤ 11  free(wasA8) 28 ├───  GPIO16   D4
              GND  ───┤ 12              27 ├───  GPIO4    D0
           GPIO25  ───┤ 13  DAC1 audio  26 ├───  GPIO0    free (boot strap)
           GPIO26  ───┤ 14  free(DAC2)  25 ├───  GPIO2    PHI2
              GND  ───┤ 15              24 ├───  GPIO15   R/W
           GPIO14  ───┤ 16  free(wasA?) 23 ├───  GPIO13   D2
              GND  ───┤ 17              22 ├───  GND
           GPIO12  ───┤ 18  free        21 ├───  (flash — do not use)
              5V   ───┤ 19              20 ├───  (flash — do not use)
                      └────────────────────┘
```

> Rows 20–22 (GPIO 6–11) are tied to internal SPI flash and must not be used.

---

## SID Register Map ($D500–$D51E)

| Offset | Address | Register | Description |
|---|---|---|---|
| $00 | $D500 | V1_FREQ_LO  | Voice 1 frequency low byte |
| $01 | $D501 | V1_FREQ_HI  | Voice 1 frequency high byte |
| $02 | $D502 | V1_PW_LO | Voice 1 pulse width low |
| $03 | $D503 | V1_PW_HI | Voice 1 pulse width high |
| $04 | $D504 | V1_CTRL | Voice 1 control (bit 0 = GATE, bit 6 = SQR) |
| $05 | $D505 | V1_AD | Voice 1 Attack/Decay |
| $06 | $D506 | V1_SR | Voice 1 Sustain/Release |
| $07 | $D507 | V2_FREQ_LO  | Voice 2 frequency low byte |
| $08 | $D508 | V2_FREQ_HI  | Voice 2 frequency high byte |
| $09 | $D509 | V2_PW_LO | Voice 2 pulse width low |
| $0A | $D50A | V2_PW_HI | Voice 2 pulse width high |
| $0B | $D50B | V2_CTRL | Voice 2 control |
| $0C | $D50C | V2_AD | Voice 2 Attack/Decay |
| $0D | $D50D | V2_SR | Voice 2 Sustain/Release |
| $0E | $D50E | V3_FREQ_LO  | Voice 3 frequency low byte |
| $0F | $D50F | V3_FREQ_HI  | Voice 3 frequency high byte |
| $10 | $D510 | V3_PW_LO | Voice 3 pulse width low |
| $11 | $D511 | V3_PW_HI | Voice 3 pulse width high |
| $12 | $D512 | V3_CTRL | Voice 3 control |
| $13 | $D513 | V3_AD | Voice 3 Attack/Decay |
| $14 | $D514 | V3_SR | Voice 3 Sustain/Release |
| $15 | $D515 | FC_LO | Filter cutoff low (not emulated) |
| $16 | $D516 | FC_HI | Filter cutoff high (not emulated) |
| $17 | $D517 | RES_FILT | Filter resonance/routing (not emulated) |
| $18 | $D518 | MODE_VOL | Master volume (bits 3:0, range 0–15) |
| $19 | $D519 | OSC3 | Voice 3 oscillator readout |
| $1A | $D51A | ENV3 | Voice 3 envelope readout |
| $1B–$1E | $D51B–$D51E | — | Unused |
| **$1F** | **$D5FF** | **LATCH** | **bit 0=1 → enable; bit 0=0 → disable+reset** |

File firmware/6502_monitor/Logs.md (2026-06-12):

# Project Logs & Architectural Decisions

## 2026-06-12: Firmware Simplification, Full 2 KB Decode, VERA Logging

### Firmware Simplification — Drop RESET / VCS / RAM Emulation
Commit `b58b0f6` removed ~165 lines of obsolete logic:
- **Dropped**: Atari RESET output, VCS output pin, RAMSEL input, the entire 512-byte emulated RAM at $D600–$D7FF.
- **Kept**: ROMSEL handler (asserts MPD, drives `pbi_rom[A0-A7]` on reads) and EXTSEL handler ($D1XX + latch).
- **Motivation**: the RAM emulation was never required by the VERA driver; removing it freed three GPIO pins and reduced the interrupt-path footprint significantly.

### Full 2 KB ROM Decode — A8, A9, A10 Wired
Commit `75b3f3e`: GPIOs 12 / 25 / 26 were freed from RESET / VCS / RAMSEL and wired to **A8 / A9 / A10**.
- `pbi_rom[]` expanded from 256 bytes to **2048 bytes** (`IRAM_ATTR`).
- `decode_addr()` now returns an **11-bit** address (A0-A10), removing the previous $D6xx/$D7xx aliasing.
- Pin definitions updated: `PIN_A8 = 12  // formerly RESET`, `PIN_A9 = 25  // formerly VCS`, `PIN_A10 = 26  // formerly RAMSEL`.
- All pin-mapping documents (PIN_MAPPING.md, PIN_MAPPING.tex, PIN_MAPPING.pdf, PIN-MAPPING.md, READMEs) regenerated to match.

### NodeMCU DevKit V1 — Sole Hardware Target
Commit `8395e40` removed the ESP32-PICO-D4 build environment from `platformio.ini`. The project now targets **NodeMCU-32S** exclusively (`nodemcu-32s` for PBI, `nodemcu-32s-cctl` for CCTL).

### FreeRTOS Log Queue
- Added a 64-entry `LogEvt` queue (Core 1 → Core 0) carrying microsecond-precision timestamps (`esp_timer_get_time()`).
- Two event types: `EVT_LATCH` (PBI latch state change) and `EVT_REG` (every $D100–$D1FE access including R/W direction and data byte).
- Core 0 `loop()` drains the queue and prints without ever blocking the bus handler.

### VERA Register Name Resolution
- Added `vera_reg_name(offset, dcsel)` lookup table in `loop()` (Core 0 only, not IRAM-resident).
- Covers all registers defined in `vera_common.inc`: `VERA_ADDR_L/M/H`, `VERA_DATA0/1`, `VERA_CTRL`, `VERA_IEN`, `VERA_ISR`; muxed DC/FX registers ($09–$0C, 7 DCSEL banks); Layer 1 registers ($14–$1A).
- DCSEL state tracked by shadowing writes to `VERA_CTRL` (offset $05, bits [2:1]) — no struct change needed.
- New serial format: `[    0.012390] [D103 - VERA_DATA0           ] W $FF`

### 6502 ROM Source Restructure
- Renamed `pbi-driver.s` → `6502/src/vera_pbi_handler.s`; extracted shared VERA symbols into `6502/src/vera_common.inc`.
- Added `pre_build.py` PlatformIO `pre:` hook — runs `make -C 6502/` before any C++ compilation.
- Makefile assembles with `ca65`, links at $D800 (2 KB) with `ld65`, converts to `include/pbi-driver.h` via `hexdump`.
- Two `platformio.ini` environments: `nodemcu-32s` (PBI, `BUS_MODE=0`) and `nodemcu-32s-cctl` (CCTL, `BUS_MODE=1`).

---

## 2026-05-08: Multi-device Bus Support
- **EXTSEL_N (EXSEL):** Switched to **Open-Drain (OD)** mode. This allows the signal to be shared with other PBI devices without hardware contention.
- **Terminology Fix:** Updated documentation to reflect that EXTSEL_N disables motherboard **memory** (not just ROM).
- **MPD & IRQ Analysis:** Confirmed IRQ is handled by the VERA FPGA and MPD is driven by the 74HCT138 hardware decoder. Clarified that sharing MPD would require hardware modifications (e.g., diodes) due to the push-pull nature of the '138.
- **Boot Integrity:** Maintained internal pull-ups and established High-Z state at boot for EXTSEL_N to ensure it doesn't interfere with the Atari startup until explicitly driven.

## 2026-05-06: High-Performance PBI Driver Implementation

### Overview
Successfully implemented a high-performance ESP32 firmware for the Atari Parallel Bus Interface (PBI). The final architecture prioritizes low latency and thread safety using a combination of external hardware decoding and FreeRTOS synchronization.

### Final Hardware Mapping
The system uses an external **74HC138** decoder for the `$D800-$DFFF` range to reduce ESP32 pin usage and latency.

#### 74HC138 Wiring (External Decoder)
| Pin 74HC138 | Signal / Connection | Function |
| :--- | :--- | :--- |
| 1 (A) | **A11** (Atari) | Address selector bit 0 |
| 2 (B) | **A12** (Atari) | Address selector bit 1 |
| 3 (C) | **A14** (Atari) | Address selector bit 2 |
| 4 (G2A) | **A13** (Atari) | Enable (Active LOW) - Must be 0 |
| 5 (G2B) | **GND** | Enable (Active LOW) - Always GND |
| 6 (G1) | **A15** (Atari) | Enable (Active HIGH) - Must be 1 |
| 7 (Y7) | **ROM_SEL / MPD** | **Output**: Active LOW for $D800-$DFFF |
| 8 (GND) | **GND** | Common Ground |
| 16 (VCC) | **+5V** (Atari) | Power Supply |

**Connection Notes:**
- **MPD:** Connect Pin 7 (Y7) directly to Atari Bus MPD line.
- **ROM_SEL:** Connect Pin 7 (Y7) to ESP32 **GPIO 4** (via 5V->3.3V Level Shifter).

#### ESP32 Pinout
| Signal | ESP32 GPIO | Direction | Description |
| :--- | :--- | :--- | :--- |
| **Data Bus (D0-D7)** | 18, 19, 21-23, 25-27 | Bidirectional | Direct register access for latency < 50ns |
| **Address (A0-A5)** | 32-36, 39 | Input | Lower 6 bits for ROM indexing |
| **Address (A6-A10)** | 16, 17, 14, 12, 13 | Input | Higher 5 bits for 2KB ROM indexing |
| **PHI2** | 2 | Input | 6502 Clock (Sync trigger) |
| **R/W** | 15 | Input | High = Read, Low = Write |
| **D1XX** | 5 | Input | Device Selection Page (Active Low) |
| **ROM_SEL** | 4 | Input | Active Low from 74HC138 ($D800-$DFFF) |
| **EXTSEL** | 0 | Output | External Select (Active Low) to Atari |
| **MPD** | - | Hardware | Managed directly by 74HC138 Y7 output |
| **Debug Serial TX** | 1 (TX) | Output | Standard Serial Debug enabled |
| **DEV_SEL / CS** | 3 | Output | Chip Select hardware ($D100-$D11F, A0-A4) |
| **Internal Regs** | - | Software | Registri ESP32 ($D120-$D1FE, A5-A7 coinvolti) |

### Key Architectural Decisions

1.  **Direct GPIO Register Access:**
    - Used `GPIO.in`, `GPIO.out_w1ts`, and `GPIO.out_w1tc` instead of `digitalRead/Write` or `gpio_config`.
    - Reduced I/O latency from microseconds to ~20ns, fitting within the 279ns Atari timing window.

2.  **Multicore Optimization (FreeRTOS):**
    - **Core 1 (MonitorTask):** Dedicated to the high-speed bus monitor loop. Uses a local state for `pbi_enabled` to avoid cache coherence overhead.
    - **Core 0 (System):** Handles Serial Debugging and FreeRTOS system tasks.
    - **Queue Communication:** Used `xQueueSend` and `xQueueReceive` for thread-safe state synchronization between cores. This avoids the "bruttissima" shared global variable approach.

3.  **Hardware Decoding ($D800-$DFFF):**
    - Offloading address decoding to a **74HC138** freed up 5 GPIOs and removed critical timing bottlenecks from the firmware.
    - `MPD` is now handled at hardware speed (~10ns), preventing bus contention before the ESP32 can even react.

4.  **Serial Debug Recovery:**
    - By moving `EXTSEL` and `MPD` away from GPIO 1 and 3, standard hardware serial debugging was restored, facilitating further development.

### Performance Verification
- **PHI2 sync:** Confirmed stable triggering on rising edge.
- **Data Injection:** 2KB ROM emulation serving `pbi_driver` array correctly within the PHI2 HIGH window.
- **Device Selection:** $D1FF write logic correctly enables/disables the PBI driver response.

## 2026-05-07: VERA Text Mode Boot Screen

### Overview
The 6502 PBI ROM now initializes the external VERA chip mapped at `$D100-$D11F` during driver startup. The boot sequence configures a text screen in a Commander X16-inspired style for Atari PBI/ECI usage.

### Video Initialization
- **VERA register model:** The driver now uses CX16-compatible VERA register naming, remapped to the Atari PBI window at `$D100`.
- **Screen mode:** Layer 1 text mode configured for **80x25** cells with **8x16** character geometry.
- **Display style:** Blue background, black border, white text.
- **Banner text:** The ROM writes:
  - `**** COMMANDER X16 VERA ****`
  - `PBI VIDEO INTERFACE`
  - `READY.`

### Font Handling
- The VERA bitstream does **not** provide a guaranteed ready-to-use system font after reset.
- For this reason, the ROM now loads a **minimal 8x16 font subset** into VERA VRAM at startup.
- The embedded glyph set is intentionally compact and currently covers only the characters required by the boot banner.

### ROM Size Constraint
- The 6502 PBI ROM linker configuration is now limited to **2KB** (`$0800` bytes).
- This matches the ESP32-side ROM fetch logic, which serves the driver with `offset & 0x7FF`.
- Current generated ROM size: **2048 bytes**.

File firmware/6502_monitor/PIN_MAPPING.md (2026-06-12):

# 6502 Monitor — ESP32 Pin Mapping (NodeMCU DevKit V1)

## 1. Data Bus (Bidirectional)
| 6502 Signal | ESP32 GPIO | Board Label |
| :--- | :--- | :--- |
| **D0** | GPIO 4  | D4  |
| **D1** | GPIO 5  | D5  |
| **D2** | GPIO 13 | D13 |
| **D3** | GPIO 14 | D14 |
| **D4** | GPIO 16 | RX2 |
| **D5** | GPIO 17 | TX2 |
| **D6** | GPIO 18 | D18 |
| **D7** | GPIO 19 | D19 |

## 2. Address Bus (A0-A10 — full 2 KB decode)
| 6502 Signal | ESP32 GPIO | Board Label | Note |
| :--- | :--- | :--- | :--- |
| **A0** | GPIO 34 | D34 | **Input Only** |
| **A1** | GPIO 35 | D35 | **Input Only** |
| **A2** | GPIO 36 | VP  | **Input Only** |
| **A3** | GPIO 39 | VN  | **Input Only** |
| **A4** | GPIO 32 | D32 | |
| **A5** | GPIO 33 | D33 | |
| **A6** | GPIO 21 | D21 | |
| **A7** | GPIO 27 | D27 | |
| **A8** | GPIO 12 | D12 | |
| **A9** | GPIO 25 | D25 | |
| **A10**| GPIO 26 | D26 | |

## 3. Control Signals
| Signal | ESP32 GPIO | Board Label | Dir | Description |
| :--- | :--- | :--- | :--- | :--- |
| **PHI2** | GPIO 2  | D2 | IN  | 6502 System Clock (1.79 MHz) |
| **R/W** | GPIO 15 | D15 | IN  | Read/Write |
| **SEL\_N** | GPIO 22 | D22 | IN  | $D1XX or CCTL selection (Active Low) |
| **ROMSEL** | GPIO 23 | D23 | IN  | $D800–$DFFF range (Active Low) |
| **EXTSEL** | GPIO 3  | **RX0**  | OUT | Disable Atari internal memory (Active Low) |
| **MPD** | GPIO 0  | **BOOT** | OUT | Math Pack Disable (Active Low) |

## 4. Serial Debug
| Signal | ESP32 GPIO | Board Label | Description |
| :--- | :--- | :--- | :--- |
| **TX** | GPIO 1 | TX0 | Console output (115200 bps) |

---

## Notes
- **A0-A10 decoded**: full 11-bit address covers the entire 2 KB $D800–$DFFF range without aliasing.
- **GPIO 0 (MPD / BOOT)**: the Atari's internal pull-up (isolated by TXS0108E) keeps GPIO 0 HIGH during ESP32 boot.
- **GPIO 3 (EXTSEL / RX0)**: shared with UART RX; not usable for serial input while firmware is running.
- All signals pass through **TXS0108E** bidirectional level shifters (3.3 V ↔ 5 V).

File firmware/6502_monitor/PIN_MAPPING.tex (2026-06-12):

\documentclass[a4paper,10pt]{article}
\usepackage[utf8]{inputenc}
\usepackage[english]{babel}
\usepackage{geometry}
\geometry{margin=1in}
\usepackage{booktabs}

\title{6502 Monitor -- ESP32 Pin Mapping (NodeMCU DevKit V1)}
\author{Atari ESP32 Project}
\date{\today}

\begin{document}
\maketitle

\section{Data Bus (Bidirectional)}
\begin{table}[h!]
\centering
\begin{tabular}{@{}lll@{}}
\toprule
\textbf{6502 Signal} & \textbf{ESP32 GPIO} & \textbf{Board Label} \\ \midrule
D0--D7 & GPIO 4, 5, 13, 14, 16, 17, 18, 19 & D4, D5, D13, D14, RX2, TX2, D18, D19 \\ \bottomrule
\end{tabular}
\end{table}

\section{Address Bus (A0--A10, full 2\,KB decode)}
\begin{table}[h!]
\centering
\begin{tabular}{@{}lll@{}}
\toprule
\textbf{6502 Signal} & \textbf{ESP32 GPIO} & \textbf{Board Label} \\ \midrule
A0--A3  & GPIO 34, 35, 36, 39 & D34, D35, VP, VN \quad (\textbf{Input Only}) \\
A4--A7  & GPIO 32, 33, 21, 27 & D32, D33, D21, D27 \\
A8--A10 & GPIO 12, 25, 26     & D12, D25, D26 \\ \bottomrule
\end{tabular}
\end{table}

\section{Control Signals}
\begin{table}[h!]
\centering
\begin{tabular}{@{}lllll@{}}
\toprule
\textbf{Signal} & \textbf{GPIO} & \textbf{Label} & \textbf{Dir} & \textbf{Description} \\ \midrule
PHI2   & GPIO 2  & D2       & IN  & 6502 System Clock (1.79\,MHz) \\
R/W    & GPIO 15 & D15      & IN  & Read/Write \\
SEL\_N & GPIO 22 & D22      & IN  & \$D1XX / CCTL selection (Active Low) \\
ROMSEL & GPIO 23 & D23      & IN  & \$D800--\$DFFF range (Active Low) \\
EXTSEL & GPIO 3  & \textbf{RX0}  & OUT & Disable Atari internal memory (Active Low) \\
MPD    & GPIO 0  & \textbf{BOOT} & OUT & Math Pack Disable (Active Low) \\ \bottomrule
\end{tabular}
\end{table}

\section{Notes}
\begin{itemize}
    \item \textbf{Full 2\,KB ROM:} A0--A10 are decoded, covering all 2048 addresses of the \$D800--\$DFFF range without aliasing.
    \item \textbf{GPIO\,0 (MPD / BOOT):} kept HIGH during boot by the Atari pull-up (isolated via TXS0108E).
    \item \textbf{GPIO\,3 (EXTSEL / RX0):} shared with UART\,RX; not usable for serial input at runtime.
    \item All signals pass through \textbf{TXS0108E} bidirectional level shifters (3.3\,V\,$\leftrightarrow$\,5\,V).
\end{itemize}

\end{document}

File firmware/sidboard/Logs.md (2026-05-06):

# Project Logs & Architectural Decisions - SIDBOARD

## 2026-05-06 (rev 2): cSIDLight — DAC nativo, nessuna dipendenza esterna

### Motivazione
La dipendenza da FabGL è stata rimossa. L'engine audio è ora completamente
autonomo e integrato nella classe `cSIDLight`. Il motivo principale è la
**garanzia del campionamento del bus Atari**: FabGL imponeva l'uso di
`xQueueSend()` nel path critico di `MonitorTask`, introducendo critical sections
FreeRTOS da 1–5 µs incompatibili con il ciclo PHI2 di ~565 ns PAL.

### Architettura cSIDLight (`include/csidlight.h`)

**Uscita audio**: DAC ESP32 su **GPIO 25** via `dacWrite()`.  
**Engine**: `esp_timer` periodico a **22050 Hz** (~45 µs/campione), task su Core 0.  
**Tre voci**: oscillatori a phase accumulator a 32 bit, onda quadra, formula PAL:
```
phaseInc = (freq_hz × 2³²) / 22050
mix = 128 + Σᵢ (phaseᵢ[31] ? +volᵢ : −volᵢ)   →  clamp [0, 255]  →  DAC
```

#### Sicurezza timing bus Atari

| Metodo | Core | Costo | Note |
|:---|:---|:---|:---|
| `write(reg, val)` | 1 – MonitorTask | **~3 cicli CPU** | singola store volatile, zero FreeRTOS |
| `read(reg)` | 1 – MonitorTask | ~3 cicli CPU | singola load volatile |
| `process()` | 1 – loop() | 32 confronti byte | snapshot `_prevRegs[]`, nessuna queue |
| `_tick()` | 0 – esp_timer | ~50 ns | legge `_phaseInc[]`/`_voiceVol[]`, scrive DAC |

`write()` è ridotto a una singola istruzione `ST` — nessuna critical section,
nessun blocco, nessuna interferenza con la finestra di campionamento PHI2.

`process()` rileva i cambiamenti comparando `_regs[]` con `_prevRegs[]` e aggiorna
i parametri di sintesi (`_phaseInc[]`, `_voiceVol[]`); viene sempre preemptato da
`MonitorTask` (priorità 10) se necessario.

#### Stato condiviso cross-core

`_phaseInc[3]` e `_voiceVol[3]` sono scritti da `process()` (Core 1) e letti da
`_tick()` (Core 0). Dichiarati `volatile uint32_t`/`int32_t`: su ESP32 la DRAM
non è cachata per-core (Xtensa LX6), quindi gli accessi a 32 bit allineati sono
atomici e immediatamente visibili sull'altro core senza barriere aggiuntive.

### Mappa indirizzi $D1xx

| Indirizzo | Accesso | Descrizione |
|:---|:---|:---|
| **$D100–$D11F** | R/W (solo se abilitato) | Registri SID (cSIDLight) |
| **$D120–$D1FE** | R/W (solo se abilitato) | Registri interni ESP32 |
| **$D1FF** | W | Bit 0 = 1: abilita device; Bit 0 = 0: disabilita + reset SID |

L'abilitazione avviene scrivendo `1` nel bit 0 di `$D1FF` (identificazione
device). Tutti gli accessi a `$D100–$D1FE` sono gated su questo flag.
Quando il bit torna a `0`, `cSIDLight::reset()` silenzia le voci e azzera lo stato.

### Mappa registri SID ($D100–$D11F)

| Offset | Registro | Descrizione |
|:---|:---|:---|
| $00–$01 | V1 Freq Lo/Hi | Frequenza Voce 1 (PAL: freq_hz = reg × 985248 / 16777216) |
| $02–$03 | V1 PW Lo/Hi | Pulse Width V1 (non emulato in Light) |
| $04 | V1 CTRL | Bit 0 = GATE (on/off voce), altri bit non emulati |
| $05–$06 | V1 A/D, S/R | ADSR V1 (non emulato in Light) |
| $07–$0D | V2 | Come V1 |
| $0E–$14 | V3 | Come V1 |
| $15–$17 | FC Lo/Hi, Res/Filt | Filtro (non emulato in Light) |
| $18 | MODE/VOL | Bit 3:0 = volume master (0–15 → ±0–120 DAC) |

### Handler PBI `I:` lato Atari

Il ROM handler in `6502/src/pbi-driver.s` registra la periferica Atari **`I:`**.
Le routine `GETBYT` e `PUTBYT` usano l'**accumulatore** per il byte trasferito e
`ICAX1,X` come **offset del registro SID**.

| Routine | Parametri | Comportamento |
|:---|:---|:---|
| `PUTBYT` | `A` = valore, `ICAX1,X` = offset registro | scrive `A` in `$D100 + offset` |
| `GETBYT` | `ICAX1,X` = offset registro | legge `$D100 + offset` e restituisce il valore in `A` |
| `CLOSE` | nessuno | silenzia il SID azzerando l'intera finestra `$D100-$D11F` |

La routine `SILENCE` azzera **32 registri** (`$00-$1F`) per allinearsi alla
finestra completa esposta dal firmware ESP32 (`SID_NUM_REGS = $20`).

### Formato dump compatibile con `sid-arduino-lib`

I file dump generati per l'esempio
`daitangio/sid-arduino-lib/examples/sid_player/sid_player.ino` non contengono
32 byte per frame ma 25.

1. scrive solo i registri **`0..24`**
2. avanza di **25 byte per frame**
3. attende circa **50 Hz** (`delay(19)`) tra un frame e il successivo

Quindi il formato corretto dei dump `_dmp.h`/binari compatibili e':

- **1 frame = 25 byte**
- **registri scritti = 0..24**
- **timing = 1 frame ogni tick video circa**

Per questo motivo gli esempi in:

- `examples/atari-basic/sid_dump_player.bas`
- `examples/cc65/sid_dump_player.c`

trattano il file come una sequenza di frame da **25 byte**, impostano
`ICAX1`/`aux1` con il registro `0..24` e aspettano un tick video tra i frame.

---

## 2026-05-06 (rev 1): Trasformazione in Sidboard

### Overview
Il progetto è stato evoluto da `6502_monitor` a `sidboard`. Obiettivo: integrare
l'emulazione **SID (MOS 6581/8580)** mantenendo il bus monitor PBI/ECI ad alta velocità.

### Key Changes
1. **Pin Reconfiguration**:
   - **Data Bus D5** spostato su **GPIO 3** (ex RX/DEV_SEL).
   - **GPIO 25 (DAC1)** liberato per l'uscita audio.
   - Rimosso `PIN_DEV_SEL`.
2. **Audio Engine**: `cSIDLight` autonoma su DAC GPIO 25 + `esp_timer`.
3. **Multicore**: `MonitorTask` su Core 1 (timing bus); `esp_timer`/audio su Core 0.

### Hardware Mapping

#### ESP32 Pinout (Sidboard)
| Signal | GPIO | Dir | Descrizione |
|:---|:---|:---|:---|
| Data Bus D0–D4 | 18, 19, 21, 22, 23 | Bidirezionale | Bus dati Atari |
| Data Bus D5 | **3** | Bidirezionale | Spostato da 25 per liberare DAC1 |
| Data Bus D6–D7 | 26, 27 | Bidirezionale | Bus dati Atari |
| Audio Output | **25 (DAC1)** | Output | SID Mono (3 voci mixate) |
| Address A0–A5 | 32–36, 39 | Input | Bus indirizzi |
| Address A6–A10 | 16, 17, 14, 12, 13 | Input | Bus indirizzi |
| PHI2 | 2 | Input | Clock 6502 (trigger sync) |
| R/W | 15 | Input | High = Read, Low = Write |
| D1XX | 5 | Input | Selezione pagina device (Active Low) |
| ROM_SEL | 4 | Input | Active Low da 74HC138 ($D800–$DFFF) |
| EXTSEL | 0 | Output | External Select (Active Low) verso Atari |
| Serial TX | 1 | Output | Debug seriale TX-Only |

### Performance & Timing
- **Bus latency**: < 50 ns per l'iniezione dati.
- **write() overhead**: ~3 cicli CPU (singola store) — nessun impatto sul PHI2.
- **Audio sample rate**: 22050 Hz via `esp_timer` su Core 0.
- **Multicore**: MonitorTask fisso su Core 1; audio e system task su Core 0.

### Circuito Audio

**Nota hardware**: GPIO 25 è connesso direttamente al TXS0108 (level translator).
Il TXS0108 è incompatibile con segnali analogici multi-livello (pull-up interni ~4 kΩ +
circuito auto-direzione). È necessario tagliare la traccia PCB tra GPIO 25 e il
pin A del TXS0108, e prelevare il segnale audio direttamente dal lato ESP32.
Dopo il taglio, il pin A del TXS0108 va pullato a GND con un resistore da 10 kΩ
per evitare che il lato B (verso l'Atari) fluttui alto.

#### Stadio 1 — Prototipo: amplificatore esterno

```
GPIO25 ──→ 10µF (DC block) ──→ 270Ω ──+──→ Amplificatore (PAM8403 o equiv.)
                                       |
                                      10nF
                                       |
                                      GND   ← LPF fc ≈ 59 kHz
```

Segnale a ~1.5 Vpp AC dopo il condensatore — sufficiente per qualsiasi ingresso
line-level o ad alta impedenza.

#### Stadio 2 — Versione finale: ECI AUDIO IN → mixer POKEY

```
GPIO25 ──→ 10µF (DC block) ──→ 100kΩ ──+──→ ECI AUDIO IN (POKEY pin 3)
                                        |
                                    10kΩ ╪ 10nF   ← in parallelo, fc ≈ 1.75 kHz
                                        |
                                       GND
```

Il 10nF in parallelo al 10kΩ forma un filtro passa-basso insieme alla sorgente
(100kΩ): fc = (100k+10k)/(2π × 100k×10k × 10nF) ≈ **1.75 kHz**.

Il segnale SID si somma direttamente alle voci POKEY nel mixer interno;
l'uscita audio dell'Atari (TV/monitor) porta SID + POKEY senza amplificatori
esterni. Nessuna traduzione di livello necessaria: AUDIO IN è un ingresso
analogico ad alta impedenza, non un segnale bus digitale.

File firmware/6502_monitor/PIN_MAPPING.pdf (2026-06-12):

# 6502 Monitor – ESP32 Pin Mapping (NodeMCU DevKit V1)

Atari ESP32 Project

June 12, 2026

## 1 Data Bus (Bidirectional)

6502 Signal | ESP32 GPIO | Board Label
D0–D7 | GPIO 4, 5, 13, 14, 16, 17, 18, 19 | D4, D5, D13, D14, RX2, TX2, D18, D19

## 2 Address Bus (A0–A10, full 2 KB decode)

6502 Signal | ESP32 GPIO | Board Label
A0–A3 | GPIO 34, 35, 36, 39 | D34, D35, VP, VN | (Input Only)
A4–A7 | GPIO 32, 33, 21, 27 | D32, D33, D21, D27
A8–A10 | GPIO 12, 25, 26 | D12, D25, D26

## 3 Control Signals

Signal | GPIO | Label | Dir | Description
PHI2 | GPIO 2 | D2 | IN | 6502 System Clock (1.79 MHz)
R/W | GPIO 15 | D15 | IN | Read/Write
SEL N | GPIO 22 | D22 | IN | $D1XX / CCTL selection (Active Low)
ROMSEL | GPIO 23 | D23 | IN | $D800–$DFFF range (Active Low)
EXTSEL | GPIO 3 | RX0 | OUT | Disable Atari internal memory (Active Low)
MPD | GPIO 0 | BOOT | OUT | Math Pack Disable (Active Low)

## 4 Notes

Full 2 KB ROM: A0–A10 are decoded, covering all 2048 addresses of the $D800–$DFFF range without aliasing.

GPIO 0 (MPD / BOOT): kept HIGH during boot by the Atari pull-up (isolated via TXS0108E).

GPIO 3 (EXTSEL / RX0): shared with UART RX; not usable for serial input at runtime.

All signals pass through TXS0108E bidirectional level shifters (3.3 V ↔5 V).

1

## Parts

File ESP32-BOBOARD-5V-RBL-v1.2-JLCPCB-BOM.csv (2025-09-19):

Comment | Designator | Footprint | LCSC
100uF | C1,C2,C3,C4,C5,C6,C7,C8,C9 | Capacitor_SMD:C_0805_2012Metric_Pad1.18x1.45mm_HandSolder | C141660
100nF | C10 | Capacitor_SMD:C_0805_2012Metric_Pad1.18x1.45mm_HandSolder | C840116
CONN_02x16_PIN_SMD_Counter_Clockwise | J3 | Connector_PinHeader_2.54mm:PinHeader_2x16_P2.54mm_Vertical_SMD | C6332241
Conn_01x03_Male | J4 | Connector_PinHeader_2.54mm:PinHeader_1x03_P2.54mm_Vertical_SMD_Pin1Left | C41417360
DX07S016JA1R1500 | J5 | RetroBitLab:JAE_DX07S016JA1R1500 | C3197885
10K | R1,R2,R3,R4 | Resistor_SMD:R_0805_2012Metric_Pad1.20x1.40mm_HandSolder | C84376
5K1 | R5,R6 | Resistor_SMD:R_0805_2012Metric_Pad1.20x1.40mm_HandSolder | C27834
CREZ08051% | R7,R8 | Resistor_SMD:R_0805_2012Metric_Pad1.20x1.40mm_HandSolder | C328378
SPST_SWITCH_SMD_4P,4.1x5.4mm | SW1 | RetroBitLab:SW_DIP_SPSTx02_DSHP02TS-S | C319052
TXS0108EPW | U1,U3,U4 | Package_SO:TSSOP-20_4.4x6.5mm_P0.65mm | C17206

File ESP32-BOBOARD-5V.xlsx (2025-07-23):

Comment | Designator | Footprint | LCSC
100uF | C1,C2,C3,C4,C5,C6,C7,C8,C9 | Capacitor_SMD:C_1210_3225Metric_Pad1.33x2.70mm_HandSolder | C49066
100nF | C10 | Capacitor_SMD:C_1210_3225Metric_Pad1.33x2.70mm_HandSolder | C436244
Conn_01x15 | J1,J2 | Connector_PinSocket_2.54mm:PinSocket_1x15_P2.54mm_Vertical
Conn_02x16_Counter_Clockwise | J3 | Connector_PinHeader_2.54mm:PinHeader_2x16_P2.54mm_Vertical_SMD | C3294474
Conn_01x03_Male | J4 | Connector_PinHeader_2.54mm:PinHeader_1x03_P2.54mm_Vertical_SMD_Pin1Left | C41417360
DX07S016JA1R1500 | J5 | RetroBitLab:JAE_DX07S016JA1R1500 | C3197885
LOGO | L1 | Symbol:KiCad-Logo2_5mm_SilkScreen
10K | R1,R2,R3,R4 | Resistor_SMD:R_1210_3225Metric_Pad1.30x2.65mm_HandSolder | C2078159
5.1K | R5,R6 | Resistor_SMD:R_1210_3225Metric_Pad1.30x2.65mm_HandSolder | C2933822
0R | R7,R8 | Resistor_SMD:R_1210_3225Metric_Pad1.30x2.65mm_HandSolder | C2907543
TXS0108EPW | U1,U3,U4 | Package_SO:TSSOP-20_4.4x6.5mm_P0.65mm | C17206

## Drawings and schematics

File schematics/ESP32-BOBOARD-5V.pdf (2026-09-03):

# B8 12 B7 13 B6 14 B5 15 B4 16 B3 17 B2 18

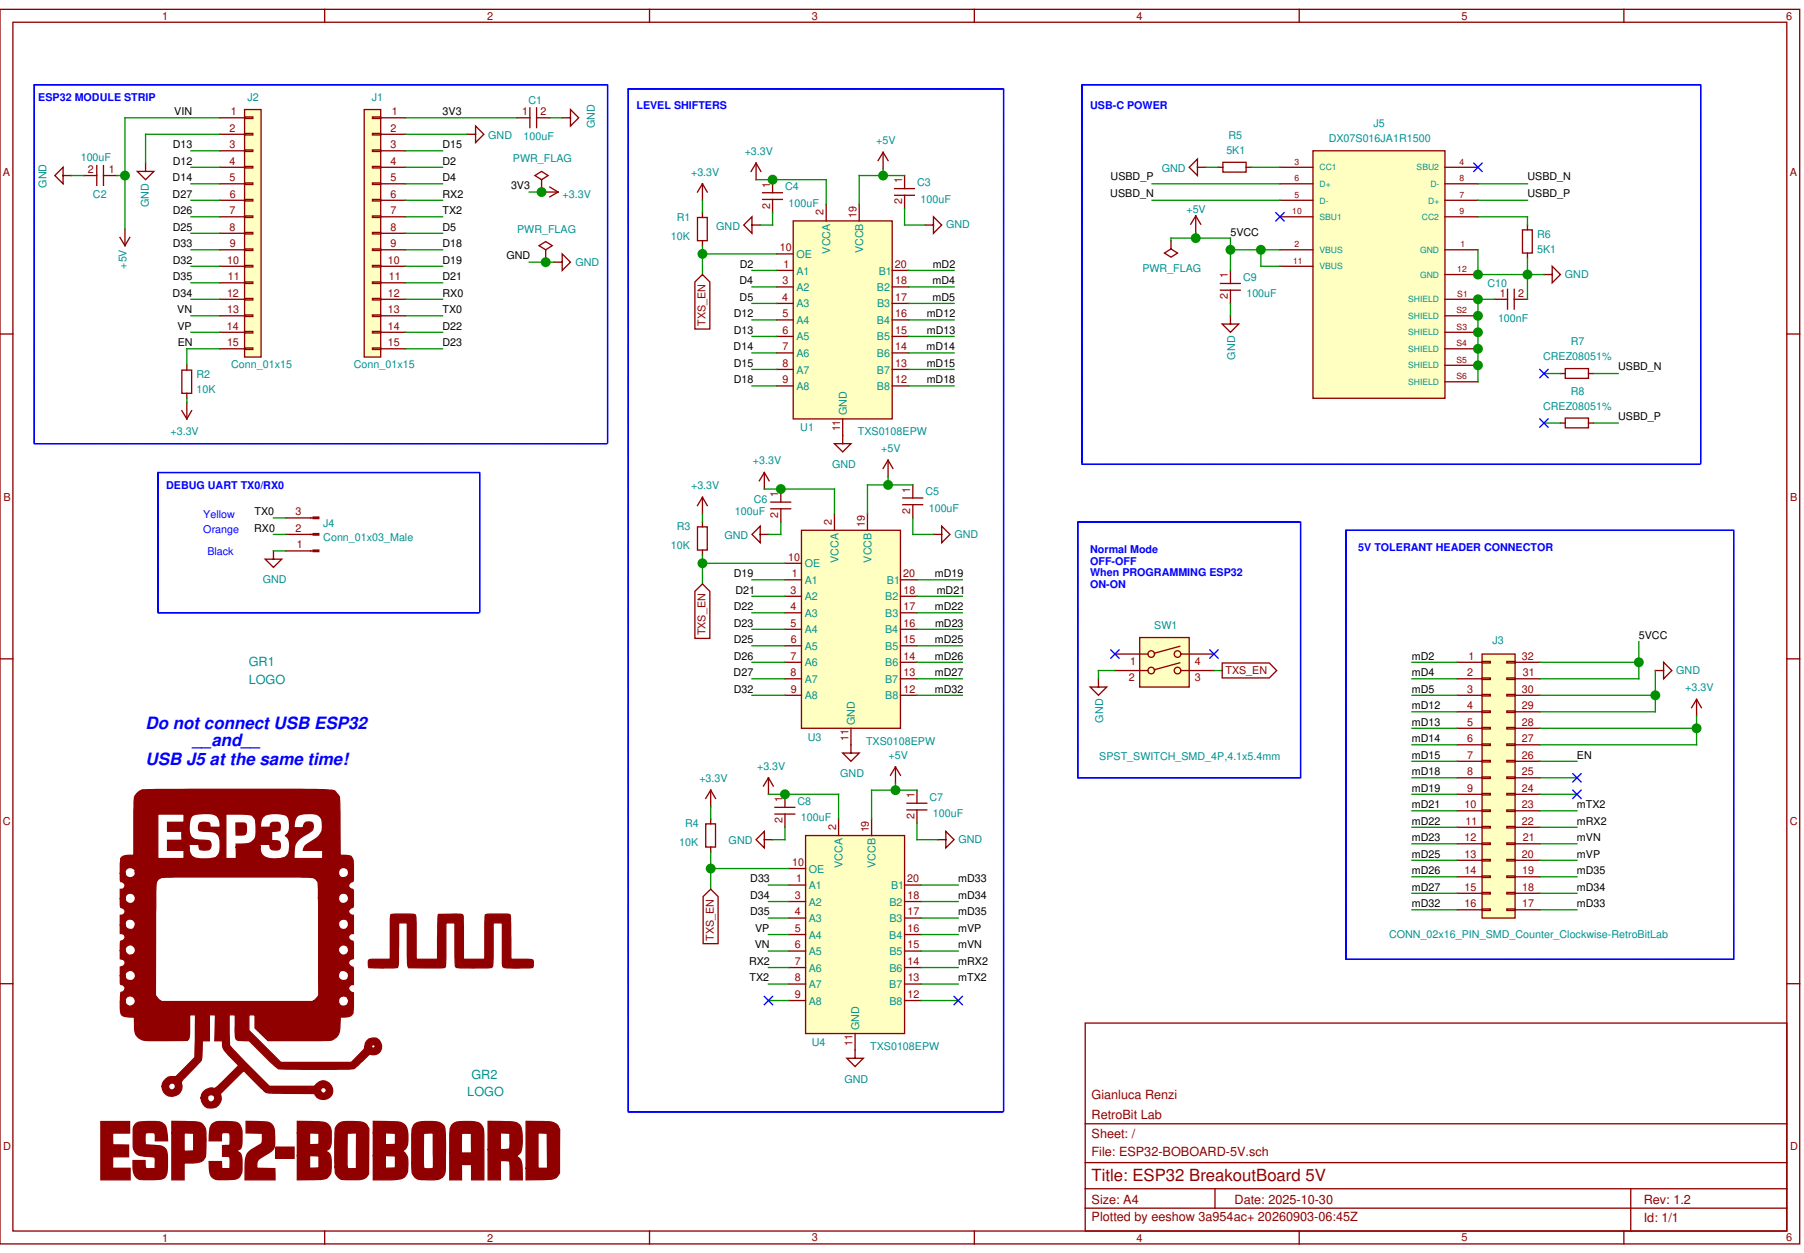
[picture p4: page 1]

Do not connect USB ESP32
__and__
USB J5 at the same time!

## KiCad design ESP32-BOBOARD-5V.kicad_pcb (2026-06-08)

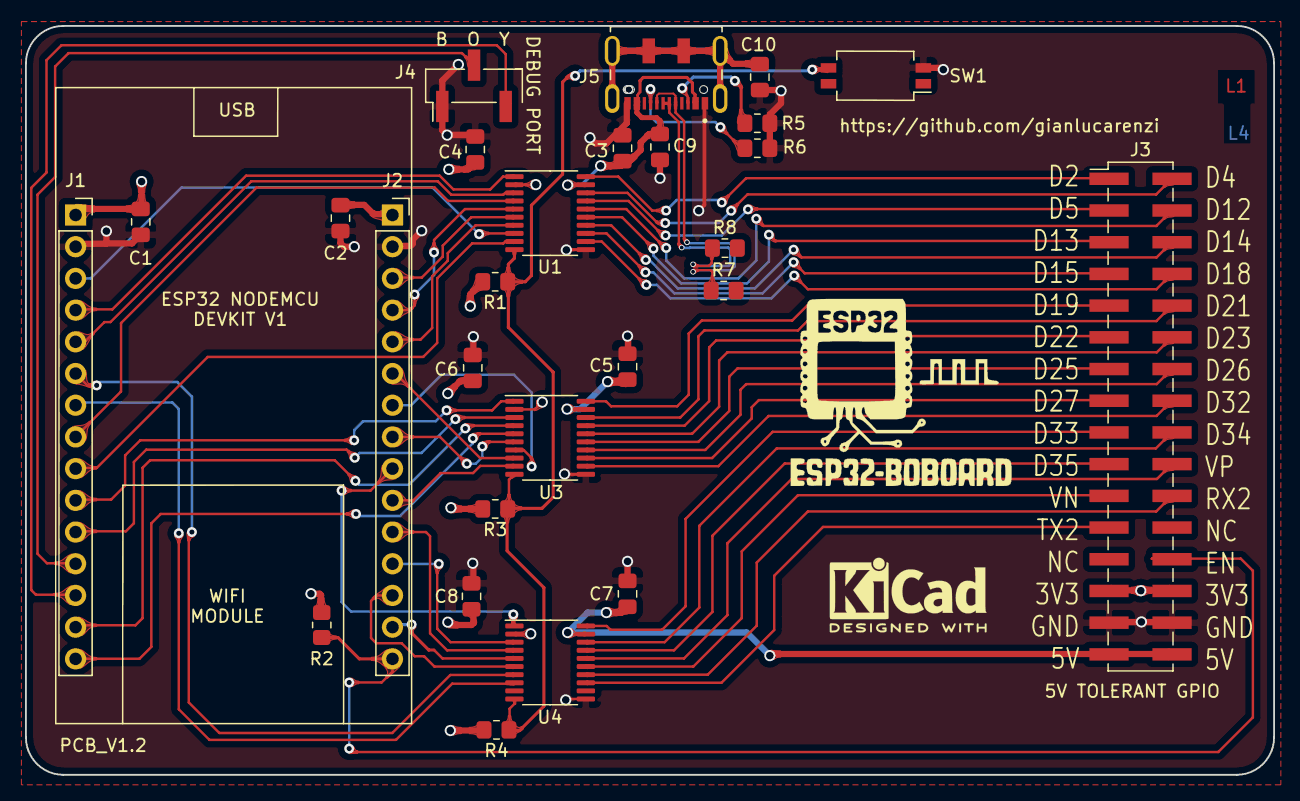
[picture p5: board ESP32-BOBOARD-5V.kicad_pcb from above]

Board: 4 copper layers, 100.0 x 60.0 mm, 29 parts (0 on the bottom side), 58 nets.

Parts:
C1, C2, C3, C4, C5, C6, C7, C8, C9: 100uF; C_0805_2012Metric_Pad1.18x1.45mm_HandSolder
C10: 100nF; C_0805_2012Metric_Pad1.18x1.45mm_HandSolder
GR1: LOGO; KiCad-Logo2_5mm_SilkScreen
GR2: LOGO; ESP32_BOBOARD_5V_21.7mmx21.7mm
J1, J2: Conn_01x15; PinSocket_1x15_P2.54mm_Vertical
J3: CONN_02x16_PIN_SMD_Counter_Clockwise-RetroBitLab; PinHeader_2x16_P2.54mm_Vertical_SMD
J4: Conn_01x03_Male; PinHeader_1x03_P2.54mm_Vertical_SMD_Pin1Left
J5: DX07S016JA1R1500; JAE_DX07S016JA1R1500
R1, R2, R3, R4: 10K; R_0805_2012Metric_Pad1.20x1.40mm_HandSolder
R5, R6: 5K1; R_0805_2012Metric_Pad1.20x1.40mm_HandSolder
R7, R8: CREZ08051%; R_0805_2012Metric_Pad1.20x1.40mm_HandSolder
SW1: SPST_SWITCH_SMD_4P,4.1x5.4mm; SW_DIP_SPSTx02_DSHP02TS-S
U1, U3, U4: TXS0108EPW; TSSOP-20_4.4x6.5mm_P0.65mm

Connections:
+3V3: C1.1, C4.1, C6.1, C8.1, J1.1, J3.27, J3.28, R1.2, R2.2, R3.2, R4.2, U1.2, U3.2, U4.2
+5V: C2.1, C3.1, C5.1, C7.1, C9.1, J2.1, J3.31, J3.32, J5.2, J5.11, U1.19, U3.19, U4.19
/D2: J1.4, U1.1
/D4: J1.5, U1.3
/D5: J1.8, U1.4
/D12: J2.4, U1.5
/D13: J2.3, U1.6
/D14: J2.5, U1.7
/D15: J1.3, U1.8
/D18: J1.9, U1.9
/D19: J1.10, U3.1
/D21: J1.11, U3.3
/D22: J1.14, U3.4
/D23: J1.15, U3.5
/D25: J2.8, U3.6
/D26: J2.7, U3.7
/D27: J2.6, U3.8
/D32: J2.10, U3.9
/D33: J2.9, U4.1
/D34: J2.12, U4.3
/D35: J2.11, U4.4
/EN: J2.15, J3.26, R2.1
/RX0: J1.12, J4.2
/RX2: J1.6, U4.7
/TX0: J1.13, J4.3
/TX2: J1.7, U4.8
/USBD_N: J5.5, J5.8, R7.1
/USBD_P: J5.6, J5.7, R8.1
/VN: J2.13, U4.6
/VP: J2.14, U4.5
/mD2: J3.1, U1.20
/mD4: J3.2, U1.18
/mD5: J3.3, U1.17
/mD12: J3.4, U1.16
/mD13: J3.5, U1.15
/mD14: J3.6, U1.14
/mD15: J3.7, U1.13
/mD18: J3.8, U1.12
/mD19: J3.9, U3.20
/mD21: J3.10, U3.18
/mD22: J3.11, U3.17
/mD23: J3.12, U3.16
/mD25: J3.13, U3.15
/mD26: J3.14, U3.14
/mD27: J3.15, U3.13
/mD32: J3.16, U3.12
/mD33: J3.17, U4.20
/mD34: J3.18, U4.18
/mD35: J3.19, U4.17
/mRX2: J3.22, U4.14
/mTX2: J3.23, U4.13
/mVN: J3.21, U4.15
/mVP: J3.20, U4.16
GND: C1.2, C2.2, C3.2, C4.2, C5.2, C6.2, C7.2, C8.2, C9.2, C10.2, J1.2, J2.2, J3.29, J3.30, J4.1, J5.1, J5.12, R5.2, R6.1, SW1.2, U1.11, U3.11, U4.11
unnamed: C10.1, J5.S1, J5.S2, J5.S3, J5.S4, J5.S5, J5.S6
unnamed: J5.3, R5.1
unnamed: J5.9, R6.2
TXS_EN: R1.1, R3.1, R4.1, SW1.3, U1.10, U3.10, U4.10

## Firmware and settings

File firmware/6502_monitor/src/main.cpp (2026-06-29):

/**
 * 6502_monitor -- ESP32 PBI ROM Emulator ($D800-$DFFF)
 *
 * FIRMWARE: Targets NodeMCU DevKit V1 (ESP32-WROOM).
 *
 * BEHAVIOUR:
 * - ROMSEL ($D800-$DFFF): asserts MPD low; drives pbi_rom[A0-A10] on reads.
 *   Full 2 KB addressing via A0-A10 (no aliasing).
 * - EXTSEL ($D1XX): asserted low when the internal latch is active.
 * - Latch (PBI mode):  set by writing $80 to $D1FF, cleared by any other value.
 * - Latch (CCTL mode): same mechanism, latch address is $D5FF instead of $D1FF.
 * - LOG: FreeRTOS queue from Core 1 to Core 0; prints VCS latch changes
 *   and every $D100-$D1FE read/write access.
 */

#include <Arduino.h>
#include <driver/gpio.h>
#include <soc/gpio_struct.h>

#include "freertos/FreeRTOS.h"
#include "freertos/task.h"
#include "freertos/queue.h"
#include <esp_timer.h>
#include "pbi-driver.h"

// ---------------------------------------------------------------------------
// Bus Protocol Mode
// ---------------------------------------------------------------------------
#define BUS_MODE_PBI  0  // Parallel Bus Interface (Atari XL/XE)
#define BUS_MODE_CCTL 1  // Cartridge Control (Cartridge Slot)

#ifndef BUS_MODE
#define BUS_MODE BUS_MODE_PBI
#endif

// ---------------------------------------------------------------------------
// Pin Definitions (NodeMCU DevKit V1 / ESP32-WROOM)
// ---------------------------------------------------------------------------
// Data Bus (D0-D7)
#define PIN_D0 4
#define PIN_D1 5
#define PIN_D2 13
#define PIN_D3 14
#define PIN_D4 16
#define PIN_D5 17
#define PIN_D6 18
#define PIN_D7 19
// Address Bus (A6-A10)
#define PIN_A6  21
#define PIN_A7  27
#define PIN_A8  12  // formerly RESET
#define PIN_A9  25  // formerly VCS
#define PIN_A10 26  // formerly RAMSEL
// PBI / Control
#define PIN_SEL_N  22  // $D1XX / CCTL selection (Active LOW, Input)
#define PIN_ROMSEL 23  // $D800-$DFFF range select (Active LOW, Input)
// Outputs
#define PIN_EXTSEL 3   // Disable Atari internal memory (Active LOW, Output)
#define PIN_MPD    0   // Math Pack Disable (Active LOW, Output)
// Common Bus Signals
#define PIN_PHI2   2   // 6502 Phase 2 Clock (1.79 MHz)
#define PIN_RW     15  // Read/Write (High = Read, Low = Write)
// Address Pins (A0-A5)
#define PIN_A0 34
#define PIN_A1 35
#define PIN_A2 36
#define PIN_A3 39
#define PIN_A4 32
#define PIN_A5 33

static const uint8_t DBUS_PINS[8] = {4, 5, 13, 14, 16, 17, 18, 19};

#define DBUS_MASK                                                          \
    ((1UL << 4) | (1UL << 5) | (1UL << 13) | (1UL << 14) | (1UL << 16) | \
     (1UL << 17) | (1UL << 18) | (1UL << 19))

// ---------------------------------------------------------------------------
// Log Queue (Core 1 → Core 0)
// ---------------------------------------------------------------------------
#define LOG_QUEUE_SIZE 64

#define EVT_LATCH 0   // VCS latch state change
#define EVT_REG   1   // $D100-$D1FE register access

// flags: bit 0 = 1→write / 0→read   bit 1 = latch state (EVT_LATCH only)   bit 2 = MPD asserted (LO)   bit 3 = EXTSEL asserted (LO)
typedef struct {
    uint64_t ts_us;   // timestamp: microseconds since boot (esp_timer_get_time())
    uint8_t  type;
    uint8_t  offset;  // register offset within $D1XX (0x00-0xFE)
    uint8_t  data;
    uint8_t  flags;
} LogEvt;

static QueueHandle_t log_queue;

// ---------------------------------------------------------------------------
// PBI ROM & Drive LUT
// ---------------------------------------------------------------------------
// Full 2 KB ROM image in IRAM — A0-A10 decoded, no aliasing.
static IRAM_ATTR uint8_t pbi_rom[2048];

// Drive LUT: byte value → 32-bit GPIO bitmask for <50 ns data bus writes.
static IRAM_ATTR uint32_t drive_lut[256];

// Internal device-active latch.
volatile bool latch_active = false;

// ---------------------------------------------------------------------------
// Decoding Helpers (IRAM)
// ---------------------------------------------------------------------------
static inline uint8_t IRAM_ATTR decode_data(uint32_t lo)
{
    return (uint8_t)(((lo >> 4) & 1) | ((lo >> 5) & 1) << 1 |
                     ((lo >> 13) & 1) << 2 | ((lo >> 14) & 1) << 3 |
                     ((lo >> 16) & 1) << 4 | ((lo >> 17) & 1) << 5 |
                     ((lo >> 18) & 1) << 6 | ((lo >> 19) & 1) << 7);
}

// Returns an 11-bit address (A0-A10) for indexing pbi_rom[].
static inline uint16_t IRAM_ATTR decode_addr(uint32_t lo, uint32_t hi)
{
    // A0-A5: GPIO_IN1_REG (GPIO 32-39 → bits 0-7 of hi)
    uint16_t a = (uint16_t)(((hi >> 2) & 1) | ((hi >> 3) & 1) << 1 |
                             ((hi >> 4) & 1) << 2 | ((hi >> 7) & 1) << 3 |
                             ((hi >> 0) & 1) << 4 | ((hi >> 1) & 1) << 5);
    // A6-A7: GPIO_IN_REG
    a |= ((lo >> 21) & 1) << 6 | ((lo >> 27) & 1) << 7;
    // A8-A10: GPIO_IN_REG (GPIO 12, 25, 26)
    a |= ((lo >> 12) & 1) << 8 | ((lo >> 25) & 1) << 9 | ((lo >> 26) & 1) << 10;
    return a;
}

static inline void IRAM_ATTR bus_drive(uint8_t val)
{
    uint32_t m       = drive_lut[val];
    GPIO.out_w1tc    = DBUS_MASK & ~m;
    GPIO.out_w1ts    = m;
    GPIO.enable_w1ts = DBUS_MASK;
}

static inline void IRAM_ATTR bus_release()
{
    GPIO.enable_w1tc = DBUS_MASK;
}

// Helper: enqueue a log event without blocking (drops if queue full).
static inline void IRAM_ATTR log_send(uint8_t type, uint8_t offset,
                                      uint8_t data, uint8_t flags)
{
    LogEvt evt = {(uint64_t)esp_timer_get_time(), type, offset, data, flags};
    xQueueSend(log_queue, &evt, 0);
}

// ============================================================================
// MonitorTask -- Core 1 High-Speed Bus Handler
// ============================================================================
void IRAM_ATTR MonitorTask(void *pvParameters)
{
    uint32_t lo, hi;
    uint16_t addr;

    const uint32_t m_phi2   = (1UL << PIN_PHI2);
    const uint32_t m_rw     = (1UL << PIN_RW);
    const uint32_t m_sel    = (1UL << PIN_SEL_N);
    const uint32_t m_romsel = (1UL << PIN_ROMSEL);
    const uint32_t m_mpd    = (1UL << PIN_MPD);
    const uint32_t m_extsel = (1UL << PIN_EXTSEL);

    // Initial state: outputs inactive (HIGH)
    GPIO.out_w1ts = m_mpd | m_extsel;

    while (true)
    {
        // 1. Sync on PHI2 rising edge
        while (!(GPIO.in & m_phi2))
            ;

        // 2. Sample address and control lines
        lo   = GPIO.in;
        hi   = GPIO.in1.val;
        addr = decode_addr(lo, hi);

        // 3. ROMSEL active ($D800-$DFFF): assert MPD, serve ROM on reads
        if (!(lo & m_romsel))
        {
            GPIO.out_w1tc = m_mpd;
            if (lo & m_rw)
                bus_drive(pbi_rom[addr & 0x7FF]);
        }
        else
        {
            GPIO.out_w1ts = m_mpd;
        }

        // 4. SEL_N active ($D1XX / CCTL): assert EXTSEL if latch is set
        if (!(lo & m_sel))
        {
            if (latch_active)
                GPIO.out_w1tc = m_extsel;

            uint8_t offset = addr & 0xFF;

            if (offset == 0xFF)
            {
                // $D1FF (PBI) / $D5FF (CCTL): latch control — only on writes
                if (!(lo & m_rw))
                {
                    uint8_t data     = decode_data(GPIO.in);
                    bool    prev     = latch_active;
                    latch_active     = (data == 0x80);
                    if (!latch_active)
                        GPIO.out_w1ts = m_extsel;
                    // Log only when state changes
                    if (latch_active != prev)
                    {
                        uint8_t fl = latch_active ? 0x02 : 0x00;
                        if (!(lo & m_romsel)) fl |= 0x04;  // MPD asserted
                        if (latch_active)     fl |= 0x08;  // EXTSEL now asserted
                        log_send(EVT_LATCH, 0xFF, data, fl);
                    }
                }
            }
            else
            {
                // $D100-$D1FE (PBI) / $D500-$D5FE (CCTL): register access — log R and W
                // Re-read GPIO.in so VERA has had time to put read data on bus.
                uint8_t data = decode_data(GPIO.in);
                uint8_t fl   = (lo & m_rw) ? 0x00 : 0x01;  // 0=read, 1=write
                if (!(lo & m_romsel)) fl |= 0x04;  // MPD asserted
                if (latch_active)     fl |= 0x08;  // EXTSEL asserted (SEL_N active + latch)
                log_send(EVT_REG, offset, data, fl);
            }
        }
        else
        {
            GPIO.out_w1ts = m_extsel;
        }

        // 5. PHI2 falling edge: release data bus
        while (GPIO.in & m_phi2)
            ;
        bus_release();
    }
}

// ============================================================================
// Setup
// ============================================================================
void setup()
{
    Serial.begin(115200, SERIAL_8N1, -1, 1);
    Serial.println("\n[6502_monitor] PBI ROM Emulator booting...");

    // Create log queue before starting MonitorTask
    log_queue = xQueueCreate(LOG_QUEUE_SIZE, sizeof(LogEvt));

    // Build drive LUT
    for (int i = 0; i < 256; i++)
    {
        uint32_t m = 0;
        for (int b = 0; b < 8; b++)
            if ((i >> b) & 1) m |= (1UL << DBUS_PINS[b]);
        drive_lut[i] = m;
    }

    // Load PBI driver ROM image (generated from 6502/pbi-driver.bin via pre_build.py)
    memcpy(pbi_rom, pbi_driver, sizeof(pbi_rom));

    // Control outputs: inactive (HIGH)
    pinMode(PIN_MPD,    OUTPUT);
    digitalWrite(PIN_MPD,    HIGH);
    pinMode(PIN_EXTSEL, OUTPUT);
    digitalWrite(PIN_EXTSEL, HIGH);

    // Data bus: high-impedance inputs initially
    for (int i = 0; i < 8; i++) pinMode(DBUS_PINS[i], INPUT);

    // Address and bus control inputs
    pinMode(PIN_PHI2,   INPUT);
    pinMode(PIN_RW,     INPUT);
    pinMode(PIN_SEL_N,  INPUT);
    pinMode(PIN_ROMSEL, INPUT);
    pinMode(PIN_A0,  INPUT);
    pinMode(PIN_A1,  INPUT);
    pinMode(PIN_A2,  INPUT);
    pinMode(PIN_A3,  INPUT);
    pinMode(PIN_A4,  INPUT);
    pinMode(PIN_A5,  INPUT);
    pinMode(PIN_A6,  INPUT);
    pinMode(PIN_A7,  INPUT);
    pinMode(PIN_A8,  INPUT);
    pinMode(PIN_A9,  INPUT);
    pinMode(PIN_A10, INPUT);

    xTaskCreatePinnedToCore(MonitorTask, "Monitor", 4096, NULL,
                            configMAX_PRIORITIES - 1, NULL, 1);

    Serial.println("[6502_monitor] Running.");
    Serial.println("[6502_monitor] VCS=OFF  Latch=DISABLED");
}

// ---------------------------------------------------------------------------
// VERA register name lookup — Core 0 only, not IRAM-resident.
// Registers $09-$0C are muxed by DCSEL (bits [2:1] of VERA_CTRL, offset $05).
// ---------------------------------------------------------------------------
static const char *vera_reg_name(uint8_t offset, uint8_t dcsel)
{
    static const char *base[8] = {
        "VERA_ADDR_L",  // $00
        "VERA_ADDR_M",  // $01
        "VERA_ADDR_H",  // $02
        "VERA_DATA0",   // $03
        "VERA_DATA1",   // $04
        "VERA_CTRL",    // $05
        "VERA_IEN",     // $06
        "VERA_ISR",     // $07
    };
    if (offset < 8)
        return base[offset];

    if (offset == 0x08)
        return "VERA_IRQLINE_L";

    if (offset >= 0x09 && offset <= 0x0C)
    {
        static const char *mux[7][4] = {
            // DCSEL=0
            { "VERA_DC_VIDEO",    "VERA_DC_HSCALE",       "VERA_DC_VSCALE",       "VERA_DC_BORDER"      },
            // DCSEL=1
            { "VERA_DC_HSTART",   "VERA_DC_HSTOP",        "VERA_DC_VSTART",       "VERA_DC_VSTOP"       },
            // DCSEL=2
            { "VERA_FX_CTRL",     "VERA_FX_TILEBASE",     "VERA_FX_MAPBASE",      "VERA_FX_MULT"        },
            // DCSEL=3
            { "VERA_FX_X_INCR_L", "VERA_FX_X_INCR_H",    "VERA_FX_Y_INCR_L",    "VERA_FX_Y_INCR_H"   },
            // DCSEL=4
            { "VERA_FX_X_POS_L",  "VERA_FX_X_POS_H",     "VERA_FX_Y_POS_L",     "VERA_FX_Y_POS_H"    },
            // DCSEL=5
            { "VERA_FX_X_POS_S",  "VERA_FX_Y_POS_S",     "VERA_FX_POLY_FILL_L", "VERA_FX_POLY_FILL_H" },
            // DCSEL=6
            { "VERA_FX_CACHE_L",  "VERA_FX_CACHE_M",     "VERA_FX_CACHE_H",     "VERA_FX_CACHE_U"     },
        };
        return mux[(dcsel < 7) ? dcsel : 0][offset - 0x09];
    }

    if (offset >= 0x0D && offset <= 0x13)
    {
        static const char *l0[7] = {
            "VERA_L0_CONFIG",    // $0D
            "VERA_L0_MAPBASE",   // $0E
            "VERA_L0_TILEBASE",  // $0F
            "VERA_L0_HSCR_L",   // $10
            "VERA_L0_HSCR_H",   // $11
            "VERA_L0_VSCR_L",   // $12
            "VERA_L0_VSCR_H",   // $13
        };
        return l0[offset - 0x0D];
    }

    if (offset >= 0x14 && offset <= 0x1A)
    {
        static const char *l1[7] = {
            "VERA_L1_CONFIG",    // $14
            "VERA_L1_MAPBASE",   // $15
            "VERA_L1_TILEBASE",  // $16
            "VERA_L1_HSCR_L",   // $17
            "VERA_L1_HSCR_H",   // $18
            "VERA_L1_VSCR_L",   // $19
            "VERA_L1_VSCR_H",   // $1A
        };
        return l1[offset - 0x14];
    }

    return "?";
}

// ============================================================================
// Loop -- Core 0: drain log queue and print
// ============================================================================
void loop()
{
    // Shadow of VERA_CTRL DCSEL bits [2:1]; updated on every write to $D105.
    static uint8_t dcsel = 0;

    LogEvt evt;
    while (xQueueReceive(log_queue, &evt, pdMS_TO_TICKS(10)) == pdTRUE)
    {
        uint32_t sec = (uint32_t)(evt.ts_us / 1000000ULL);
        uint32_t us  = (uint32_t)(evt.ts_us % 1000000ULL);
        if (evt.type == EVT_LATCH)
        {
            bool enabled = (evt.flags & 0x02) != 0;
            Serial.printf("[%5lu.%06lu] [VCS ] Latch %s ($%02X written to %s) MPD=%s EXTSEL=%s\n",
                          sec, us,
                          enabled ? "ENABLED " : "DISABLED", evt.data,
                          (BUS_MODE == BUS_MODE_PBI) ? "$D1FF" : "$D5FF",
                          (evt.flags & 0x04) ? "LO" : "HI",
                          (evt.flags & 0x08) ? "LO" : "HI");
        }
        else  // EVT_REG
        {
            // Track DCSEL so muxed registers ($09-$0C) resolve correctly.
            if (evt.offset == 0x05 && (evt.flags & 0x01))
                dcsel = (evt.data >> 1) & 0x07;

            Serial.printf("[%5lu.%06lu] [D1%02X - %-20s] %c $%02X  MPD=%s EXTSEL=%s\n",
                          sec, us,
                          evt.offset,
                          vera_reg_name(evt.offset, dcsel),
                          (evt.flags & 0x01) ? 'W' : 'R',
                          evt.data,
                          (evt.flags & 0x04) ? "LO" : "HI",
                          (evt.flags & 0x08) ? "LO" : "HI");
        }
    }
}

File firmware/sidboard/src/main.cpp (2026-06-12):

/**
 * ESP32 Atari CCTL/SID Firmware - Sidboard
 *
 * ARCHITECTURE:
 * - SEL_N (GPIO 22) connected to CCTL (Cartridge Control Line, $D5xx).
 * - Core 1: MonitorTask — High-speed bus monitor, no FreeRTOS in hot path.
 * - Core 0: loop() + esp_timer (cSIDLight audio at 22050 Hz on GPIO 25).
 * - Communication: FreeRTOS queues — latchEventQueue (bool) + log_queue.
 *
 * MEMORY MAP ($D5xx via CCTL, A0-A4 decoded):
 * - $D500-$D51E  SID Registers (offsets 0x00-0x1E, 31 registers)
 * - $D5FF        Latch control: write bit 0 = 1 → enable, 0 → disable+reset
 *                (decoded as offset 0x1F — A0-A4 all high)
 */

#include <Arduino.h>
#include <driver/gpio.h>
#include <esp_timer.h>
#include <soc/gpio_reg.h>
#include <soc/gpio_struct.h>

#include "csidlight.h"
#include "freertos/FreeRTOS.h"
#include "freertos/queue.h"
#include "freertos/task.h"

cSIDLight *sidLight = nullptr;

#ifdef AUDIO_DEMO
#include "Commando_dmp.h"
static int                demo_frame   = 0;
static const int          demo_total   = sidLength / 25;
static esp_timer_handle_t demo_timer_h = nullptr;

static void demo_tick(void *)
{
    if (!sidLight) return;
    const uint8_t *f = sidData + (size_t)demo_frame * 25;
    for (uint8_t r = 0; r < 25; r++)
        sidLight->write(r, f[r]);
    if (++demo_frame >= demo_total) demo_frame = 0;
}
#endif

// ---------------------------------------------------------------------------
// Pin Definitions
// ---------------------------------------------------------------------------

// Data Bus (D0-D7)
#define PIN_D0 4
#define PIN_D1 5
#define PIN_D2 13
#define PIN_D3 14
#define PIN_D4 16
#define PIN_D5 17
#define PIN_D6 18
#define PIN_D7 19

static const uint8_t DBUS_PINS[8] = {4, 5, 13, 14, 16, 17, 18, 19};

#define DBUS_MASK \
    ((1UL << 4) | (1UL << 5) | (1UL << 13) | (1UL << 14) | \
     (1UL << 16) | (1UL << 17) | (1UL << 18) | (1UL << 19))

// Address Bus A0-A4 (GPIO_IN1_REG, GPIOs 32-39)
// A0=GPIO34, A1=GPIO35, A2=GPIO36, A3=GPIO39, A4=GPIO32
#define PIN_A0 34
#define PIN_A1 35
#define PIN_A2 36
#define PIN_A3 39
#define PIN_A4 32

// CCTL and common bus signals
#define PIN_SEL_N 22   // CCTL — $D5xx range (Active LOW, Input)
#define PIN_PHI2  2    // 6502 Phase 2 Clock (1.79 MHz PAL)
#define PIN_RW    15   // Read/Write (High = Read, Low = Write)

// GPIO 25 (formerly A9) → ESP32 DAC1, used by cSIDLight audio output.
// GPIO 26 (formerly A10), GPIO 33 (formerly A5), GPIO 21 (formerly A6),
// GPIO 27 (formerly A7), GPIO 12 (formerly A8) are available for future use.
// GPIO 0 (formerly MPD) and GPIO 3 (formerly EXTSEL) are also free.
// GPIO 23 (formerly ROMSEL) is free.

// ---------------------------------------------------------------------------
// Log Queue (Core 1 → Core 0)
// ---------------------------------------------------------------------------
#define LOG_QUEUE_SIZE 64

#define EVT_LATCH 0   // $D5FF latch state change
#define EVT_REG   1   // $D500-$D51E register access

// flags: bit 0 = 1→write / 0→read
//        bit 1 = new latch state (EVT_LATCH only: 1=enabled, 0=disabled)
typedef struct {
    uint64_t ts_us;
    uint8_t  type;
    uint8_t  offset;  // 5-bit decoded address (0x00-0x1F)
    uint8_t  data;
    uint8_t  flags;
} LogEvt;

static QueueHandle_t log_queue;
static QueueHandle_t latchEventQueue;

static IRAM_ATTR uint32_t data_set_lut[256];

static inline void IRAM_ATTR log_send(uint8_t type, uint8_t offset,
                                      uint8_t data, uint8_t flags)
{
    LogEvt evt = {(uint64_t)esp_timer_get_time(), type, offset, data, flags};
    xQueueSend(log_queue, &evt, 0);
}

// ---------------------------------------------------------------------------
// Precompute GPIO bitmask LUT for data bus writes
// ---------------------------------------------------------------------------
static void precompute_data_lut()
{
    for (int i = 0; i < 256; i++)
    {
        uint32_t mask = 0;
        for (int b = 0; b < 8; b++)
            if ((i >> b) & 1) mask |= (1UL << DBUS_PINS[b]);
        data_set_lut[i] = mask;
    }
}

// ---------------------------------------------------------------------------
// Address bus decode: A0-A4 → 5-bit offset (0x00-0x1F)
// GPIO_IN1 bit layout: GPIO32=bit0 … GPIO36=bit4, GPIO39=bit7
// ---------------------------------------------------------------------------
static inline uint8_t IRAM_ATTR decode_addr(uint32_t hi)
{
    return (uint8_t)(((hi >> 2) & 1)      |   // GPIO34 = A0
                     ((hi >> 3) & 1) << 1 |   // GPIO35 = A1
                     ((hi >> 4) & 1) << 2 |   // GPIO36 = A2
                     ((hi >> 7) & 1) << 3 |   // GPIO39 = A3
                     ((hi >> 0) & 1) << 4);   // GPIO32 = A4
}

// ---------------------------------------------------------------------------
// Data bus decode from GPIO_IN_REG
// ---------------------------------------------------------------------------
static inline uint8_t IRAM_ATTR decode_data(uint32_t lo)
{
    return (uint8_t)(((lo >> 4)  & 1)      |   // GPIO4  = D0
                     ((lo >> 5)  & 1) << 1 |   // GPIO5  = D1
                     ((lo >> 13) & 1) << 2 |   // GPIO13 = D2
                     ((lo >> 14) & 1) << 3 |   // GPIO14 = D3
                     ((lo >> 16) & 1) << 4 |   // GPIO16 = D4
                     ((lo >> 17) & 1) << 5 |   // GPIO17 = D5
                     ((lo >> 18) & 1) << 6 |   // GPIO18 = D6
                     ((lo >> 19) & 1) << 7);   // GPIO19 = D7
}

// ---------------------------------------------------------------------------
// Data bus drive helpers
// ---------------------------------------------------------------------------
static inline void IRAM_ATTR bus_drive(uint8_t val)
{
    uint32_t m       = data_set_lut[val];
    GPIO.out_w1tc    = DBUS_MASK & ~m;
    GPIO.out_w1ts    = m;
    GPIO.enable_w1ts = DBUS_MASK;
}

static inline void IRAM_ATTR bus_release()
{
    GPIO.enable_w1tc = DBUS_MASK;
}
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

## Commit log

2025-07-23 Added via UPLOAD
    [ESP32-BOBOARD-5V.csv, ESP32-BOBOARD-5V.kicad_pcb, ESP32-BOBOARD-5V.sch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]
2025-07-23 Sent to JLCPCB 23 Jul 2025 PCB V1.0
    [ESP32-BOBOARD-5V-B_Cu.gbl, ESP32-BOBOARD-5V-B_Mask.gbs, ESP32-BOBOARD-5V-B_Paste.gbp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]
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2025-07-31 AUTO TEST (Shorting IN <--> OUT)
    [main.cpp]
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2025-08-01 Added the dip-switch for programming
    [ESP32-BOBOARD-5V.csv]
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2025-09-19 Added to project. Must be checked first!
    [ESP32-BOBOARD-5V-RBL-v1.1-JLCPCB-BOM.csv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]
2025-09-19 Updated to reflect new components from library and LCSC availability
    [ESP32-BOBOARD-5V.csv, ESP32-BOBOARD-5V.kicad_pcb, ESP32-BOBOARD-5V.sch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]
2025-09-19 UUpdated to reflect new components from library and LCSC availability
    [ESP32-BOBOARD-5V-B_Cu.gbl, ESP32-BOBOARD-5V-B_Mask.gbs, ESP32-BOBOARD-5V-B_Paste.gbp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]
2025-09-19 From 1210 to 0805 as the first are pretty hard to find nowadays.
    [ESP32-BOBOARD-5V.csv]
2025-09-19 No BOTTOM components
    [ESP32-BOBOARD-5V-B_Cu.gbl, ESP32-BOBOARD-5V-B_Mask.gbs, ESP32-BOBOARD-5V-B_Paste.gbp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]
2025-10-30 Autogeneration tools
    [ESP32-BOBOARD-5V.kicad_pcb, ESP32-BOBOARD-5V.sch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]
2025-10-30 Opened/Closed for Plotting
    [ESP32-BOBOARD-5V.kicad_pcb]
2026-05-05 Corrected pin mapping with the latest version
    [main.cpp]
2026-05-06 High speed implementation of decoding logic for a PBI Device on Atari XE
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2026-05-06 Updated to emulate SID and its 32 registers. Now the SID Emulator can be used as a standard I/O IOCB Device
2026-05-08 Added IRAM_ATTR to have this driver in IRAM instead of Flash. Access time for READ/WRITE will be a lot quicker
2026-05-08 Typo and missing includes
    [main.cpp]
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2026-06-08 feat(6502_monitor): implement dual-mode bus monitor with optimized safe pinout
    - Implemented PBI (, , ) and CCTL () bus modes.
    - Added direct register access and IRAM-resident monitoring for 1.79 MHz compatibility.
    - Designed 'Safe Boot' pinout avoiding GPIO 0 and 12 bootstrap issues.
    - Reconfigured RX0 (GPIO 3) as EXTSEL output while keeping TX0 for debug.
    - Added detailed hardware documentation in Markdown and LaTeX.
    [main.cpp]
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2026-06-08 Updated for new pin mappings
    [ESP32-BOBOARD-5V.kicad_pcb, ESP32-BOBOARD-5V.sch]
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2026-06-12 build: remove ESP32-PICO-D4 support, target NodeMCU DevKit V1 only
    Drop PICO-D4 build environments, pin definitions, conditional branches,
    and mapping documents. Firmware now targets exclusively ESP32-WROOM
    on NodeMCU DevKit V1.
2026-06-12 refactor: simplify to PBI ROM emulator, drop RESET/VCS/RAM emulation
    Remove Atari RESET control, VCS output, RAMSEL and the 512-byte
    emulated RAM. The firmware now only handles:
    - ROMSEL: asserts MPD low and drives pbi_rom[A0-A7] on 6502 reads
    - EXTSEL: asserted on D1XX access when the internal latch is active
    - Latch: set/cleared via D1FF write (PBI), always on (CCTL)
    [main.cpp]
2026-06-12 docs: update READMEs and pin mapping to match simplified firmware
    Remove RAMSEL, VCS, RESET from all pin tables. Simplify firmware
    section to describe the PBI ROM emulator. Regenerate PIN_MAPPING.pdf.
2026-06-12 feat: add A8-A10 for full 2KB PBI ROM decode (no aliasing)
    Wire GPIO 12/25/26 (freed from RESET/VCS/RAMSEL) to A8/A9/A10.
    Expand pbi_rom to 2048 bytes, decode_addr now returns 11-bit address.
    Update all pin mapping docs and regenerate PDF.
    [main.cpp]
2026-06-12 build: auto-assemble PBI handler before every pio build
    Add pre_build.py extra_script: runs make -C 6502/ before linking
    the ESP32 firmware so pbi-driver.h is always up to date.
    Add 'rebuild' target to 6502/Makefile for forced manual recompile.
2026-06-12 build: fix pre-build hook to run before source compilation
    Run make in script body (load time) instead of AddPreAction
    so pbi-driver.h is assembled before any .cpp is compiled.
2026-06-12 build: switch PBI handler source to vera_pbi_handler.s
    Output remains pbi-driver.h for ESP32 firmware compatibility.
2026-06-12 feat: add FreeRTOS log queue with microsecond timestamps
    Add a 64-entry FreeRTOS queue between Core 1 (MonitorTask) and
    Core 0 (loop) to log PBI bus activity without blocking the bus handler.
    - EVT_LATCH: logged on VCS latch state changes ($D1FF writes that
    flip the latch), carrying new state and data byte
    - EVT_REG: logged on every $D100-$D1FE read or write, carrying
    register offset, data, and direction
    - Timestamp (uint64_t us) captured via esp_timer_get_time() in Core 1
    at the exact moment of the bus cycle
    - Serial output format: [seconds.microseconds] [D1xx] R/W $val
    - xQueueSend with timeout=0: events dropped when queue is full,
    MonitorTask timing is never affected
    Update READ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
    [main.cpp]
2026-06-12 docs: update README to reflect current firmware state
    Remove stale RAM emulation and A8-mirroring sections; add VERA register
    logging with FreeRTOS queue and microsecond timestamps, 6502 ROM build
    pipeline (vera_pbi_handler.s / vera_common.inc / pre_build.py), and
    platformio.ini environment table with pio run commands.
2026-06-12 feat: log VERA register names with DCSEL-aware resolution
    Add vera_reg_name() lookup table in loop() (Core 0) covering all
    named registers from vera_common.inc: ADDR_L/M/H, DATA0/1, CTRL,
    IEN, ISR, muxed DC/FX registers ($09-$0C resolved by shadowing the
    last VERA_CTRL write), and L1 layer registers ($14-$1A).
    Serial output now shows: [D103 - VERA_DATA0 ] R $FF
    Update README serial-output example accordingly.
    [main.cpp]
2026-06-12 docs: align all documentation with current firmware state
    HARDWARE.md: remove stale RAM-at-$D600-$D7FF emulation bullet; fix
    DEV_SEL_N -> SEL_N; restate overview around VERA logging and EXTSEL/MPD.
    Logs.md: add 2026-06-12 entry documenting FreeRTOS log queue with µs
    timestamps, VERA register name resolution (vera_reg_name + DCSEL shadow),
    and the 6502 ROM source restructure (vera_pbi_handler.s / vera_common.inc
    / pre_build.py / platformio.ini dual environments).
    README.md / README_EN.md: update serial-output example to new format with
    symbolic register names ([D103 - VERA_DATA0] R $FF); fix block diagram
    TXS0108E grouping (A8-A15 was wrong — corrected to A0-A7 / A8-A10+Controls);
    fix Le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
2026-06-12 docs: complete Logs.md 2026-06-12 with missing architectural changes
    Add three subsections that were not yet documented:
    - Firmware Simplification: drop RESET/VCS/RAMSEL/512-byte RAM (b58b0f6)
    - Full 2 KB ROM Decode: A8-A10 wired on freed GPIOs 12/25/26 (75b3f3e)
    - NodeMCU-only target: remove ESP32-PICO-D4 environment (8395e40)
2026-06-12 feat: log MPD and EXTSEL state on each bus event
    Aggiunge i bit 2 (MPD) e 3 (EXTSEL) al campo flags di LogEvt,
    derivati dai valori già campionati (lo, latch_active) nei call site
    della MonitorTask — senza letture GPIO aggiuntive in log_send().
    Il log mostra ora MPD=LO/HI e EXTSEL=LO/HI per ogni accesso.
2026-06-12 feat: CCTL latch toggleable via $D5FF ($80=enable, $00=disable)
    - latch_active starts always false (was always-true in CCTL mode)
    - removed #if BUS_MODE_PBI guard: offset $FF latch logic now runs in
    both PBI and CCTL modes
    - loop(): latch log prints $D1FF or $D5FF based on compile-time BUS_MODE
2026-06-12 refactor: unify 6502_monitor pin mapping, CCTL-only mode, DAC1 audio restored
    - Adopt pin mapping from 6502_monitor: data bus on GPIO 4/5/13/14/16/17/18/19,
    A0-A4 on GPIO 34/35/36/39/32, SEL_N on GPIO 22.
    - Remove ROMSEL, MPD, EXTSEL: no ROM served, no PBI output signals.
    - Remove A5-A10: only 5 address bits needed for 32 SID registers.
    - SEL_N now connected to CCTL ($D5xx range).
    - Latch control at offset 0x1F ($D5FF decoded with A0-A4 all high).
    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
2026-06-12 docs: rewrite README for CCTL/SID mode with updated pin mapping and memory map
2026-06-12 fix(csidlight): correct pitch, amplitude and oscillator phase continuity
    - SID_ACTUAL_RATE (22222 Hz) replaces SID_SAMPLE_RATE in _phaseIncFor()
    to match the real esp_timer period (45 µs, not 45.351 µs), eliminating
    the 0.78% sharp pitch error caused by integer truncation in SID_TIMER_US.
    - _masterVol() now multiplies before dividing (nibble*128/48) giving
    voiceVol up to 40 instead of 30, recovering ~33% of lost DAC amplitude.
    - _phase[] advances unconditionally in _tick(); only the mix contribution
    is skipped when voiceVol==0, keeping the oscillator running during
    gate-off as a real SID does and preventing phase-restart clicks.
2026-06-12 fix: drain log queue one entry per loop() to avoid starving process()
    Serial.printf() at 115200 baud blocks ~3.5 ms per line; draining all 64
    entries in a tight while loop could stall process() for ~220 ms, delaying
    SID register propagation to the audio engine. Switching to a single if
    bounds serial overhead to one line per loop iteration while process() runs
    at full loop rate and the queue drains gradually via its 64-entry buffer.
    [main.cpp]
2026-06-12 docs: update README with cSIDLight fixes and log drain rationale
    Document SID_ACTUAL_RATE (22222 Hz vs nominal 22050 Hz), unconditional
    phase advance in _tick(), corrected master volume formula (multiply before
    divide, max voiceVol 40 per voice), and the one-entry-per-loop log drain
    policy that prevents process() starvation during serial output.
2026-06-12 feat: AUDIO_DEMO mode — Commando SID register replay at 50 Hz
    New build environment nodemcu-32s-demo (-D AUDIO_DEMO) plays back
    Commando_dmp.h (27500 bytes, 1100 frames x 25 SID registers) via a
    dedicated esp_timer at 50 Hz (PAL VBlank rate). demo_tick() writes
    registers 0x00-0x18 to cSIDLight each frame and loops automatically.
    Commando_dmp.h: changed array type char->uint8_t and converted all
    negative initializer values to their unsigned equivalents (v+256) to
    fix C++ narrowing conversion errors; PROGMEM attribute kept as no-op.
    [main.cpp]
2026-06-29 fix(6502): set fillval=$FF in linker script; fix main.cpp CCTL comment, PBI ROM init, vera_reg_name
    - pbi-driver.ld: add fillval=$FF so padding matches EPROM-erased value
    - Regenerate pbi-driver.{bin,h} with correct fill
    - main.cpp: add #include pbi-driver.h; init pbi_rom via memcpy from pbi_driver[];
    fix CCTL header comment (same latch mechanism as PBI, address $D5FF not $D1FF);
    add VERA_IRQLINE_L ($08) and Layer 0 registers ($0D-$13) to vera_reg_name()
    [main.cpp]
2026-09-03 Fix eeplot PDF export: keep each schematic sheet's own page size
    eeplot forced every page of the exported PDF to the size of the largest
    sheet, anchoring smaller sheets top-left instead of keeping their native
    paper size (same fix as applied in Vera-Module-RBL-XE). Patch
    record_wipe()/cr_pdf_end() so each page is sized and offset from its own
    bounding box, and wire patch application into output_job.sh's eeplot
    build/update steps. Regenerated ESP32-BOBOARD-5V.pdf with the fix.
2026-10-29 output_job.sh: pass the board to clean_virtual.sh with --pcb
    As a positional argument the .kicad_pcb was treated as one more CPL CSV to
    clean: every run rewrote the board (dropping its blank lines) and left a
    new backup copy next to it.
2026-10-29 output_job.sh: run on Debian 13 and the KiCad 5 AppImage too
    Same scripts as Vera-Module-RBL-XE. They keep working on older Debian
    (system KiCad 5, Python 3.9, cairo 1.16) and also run where KiCad 5 is
    only the AppImage:
    - generate_bom.py replaces xsltproc + bom2grouped_csv_jlcpcb.xsl, which
    was missing; plain Python 3, same output byte for byte as the XSL
    - run_generate_cpl.sh uses the system pcbnew when there is one, otherwise
    "kicad5 --python" (AppImage v2.2.0+), and reports a failure instead of
    going on with stale CPL files
    - eeplot is rebuilt when its binary misses system libraries or the local
    patches change; the build checks fig2dev too
    - eeplot-kicad5-schematics.patch: find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
2026-11-01 firmware(6502_monitor): port the RBL-XE bus loop optimizations
    Adapted to the ESP32 classic (LX6: no dedicated GPIO, no ee.* instructions):
    - Core 1 belongs to the bus loop: interrupts masked, interrupt watchdog
    (MWDT1) disabled, no FreeRTOS call in the loop.
    - Lock-free SPSC log ring (1024 events, drops counted) instead of
    xQueueSend + esp_timer_get_time(); timestamps from the Core 1 CCOUNT
    extended to 64 bit.
    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
2026-11-01 firmware(6502_monitor): LogTask is the only Serial writer, one write per line
    - setup() no longer prints: LogTask prints the banner, the bus events and
    the bus loop start failure in one sequence.
    - Each line is formatted into a 128-byte local buffer and sent with a
    single Serial.write(), which holds the UART mutex for the whole call:
    lines never interleave. Print::println is two writes, and Print::printf
    mallocs every line longer than 64 bytes.
    - LOG_BAUD (default 115200) selects the log speed; a higher value only
    drops fewer events during bursts and needs a matching monitor_speed.
2026-11-01 docs(6502_monitor): no 74HC138 on this board, ROMSEL / SEL_N come from J3
    ROMSEL (GPIO 23) and SEL_N (GPIO 22) arrive on J3 pins 12 and 11 through
    U3 (TXS0108E): whether they are PHI2-qualified depends on the circuit
    connected to J3. Fix HARDWARE.md and the 2026-11-01 Logs.md entry, which
    relied on the 74HC138 described in the 2026-05-06 entry.
2026-11-01 firmware(6502_monitor): VDD_SDIO efuse check on upload, no monitor reset, no output glitch
    - efuse_vdd_sdio.py (post: script, before every upload): GPIO12 carries
    A8 and the ROM samples it at every chip reset to select the flash
    voltage (HIGH = 1.8 V, the WROOM-32 does not boot). Reads
    XPD_SDIO_FORCE/REG/TIEH: all set -> nothing to do; all blank ->
    espefuse set_flash_voltage 3.3V (irreversible) and read back; any
    other state -> upload stopped, nothing burned. Enabled by
    custom_efuse_vdd_sdio = 3.3V. espefuse runs from a private virtualenv
    in .pio/espefuse-venv (ecdsa, bitstring, reedsolo, cryptography).
    - monitor_rts = 0 / monitor_dtr = 0: opening the monitor no longer reset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
2026-11-01 firmware(6502_monitor): ROM-less PBI / CCTL peripheral on ~D1XX / ~CCTL, A0-A7
    On this board MPD (GPIO0) and EXTSEL (GPIO3) never reached the Atari and
    only one TXS0108E channel is free: without MPD the PBI ROM at $D800 would
    collide with the internal Math Pack. The ROM goes, the device stays in
    the I/O windows.
    - Signals: D0-D7, A0-A7, PHI2, R/W, ~D1XX (GPIO22) and ~CCTL (GPIO23, the
    former ROMSEL channel): 20 inputs, no output pins. Freed: GPIO12, 25, 26.
    - Two windows, $D100-$D1FF and $D500-$D5FF, each with its own select
    latch at $xxFF (bit 7, device ID $80) and a 256-byte register file
    written only by the Atari. Selected: writes stored, reads answered.
    Not selected: the bus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
2026-11-01 docs: board README and PIN-MAPPING for the ROM-less 6502_monitor firmware
    Pinout (A0-A7, ~D1XX, ~CCTL, unused GPIOs), TXS0108E channel map from the
    netlist (U1 / U3 / U4), firmware features, bus cycle, register windows,
    serial output, flow diagrams, PlatformIO configuration with the efuse
    check, 30-pin DevKit, directory tree.
2026-11-01 firmware(6502_monitor): banked RAM in the $D1xx / $D5xx windows
    Each window is independent, with its own latch, bank register and RAM:
    - $xx00-$xx7F RAM window, 128 bytes of the current bank (R/W)
    - $xxFD bank register (R/W), 256 banks = 32 KB per window
    - $xxFF select latch (W, bit 7 = device ID $80), never driven
    - $xx80-$xxFC, $xxFE reserved: never driven, writes ignored
    RAM and bank register respond only while the window is selected.
    128-byte window: one LDX #$7F / DEX / BPL loop, bank / offset by shifts.
    64 KB of DRAM .bss (104 KB static of 320 KB).
    The PHI1 decode is inline assembly: window state in a fixed-layout struct
    (RAM pointer of the current bank, latch, bank), b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
2026-11-01 firmware(6502_monitor): Atari banked RAM test, no DRAM_ATTR on large arrays
    - atari-test/banked_ram_test.s (ca65, XEX at $2E00): per window BANK REG,
    PROTECT (deselect with $7F, writes ignored, reselect with $81) and
    MARCH over all 256 banks (pattern and complement); then D1 KEEP after
    the $D5xx tests. 24-bit error counts, first four errors per test
    printed. TEST_CCTL = 0 skips $D5xx.
    - atari-test/sim_banked_ram.py: runs the XEX on py65 against a model of
    the device; ALL TESTS PASSED, and seven injected faults are all
    detected (make sim / make simall).
    - main.cpp: DRAM_ATTR placed the zeroed bank_ram (64 KB) and log_ring
    (16 KB) in .data, i.e. in the flash image and the boot-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
2026-11-01 firmware(6502_monitor): C64 GeoRAM 256 KB (DRAM + IRAM), /IOx polling as RBL-C64
    - GEORAM_KB (default 256): power-of-two size, block register masked to it
    (block 16 aliases block 0) as on a real GeoRAM; falls back to the next
    power of two if the heap is short
    - pages from DRAM first, then from the free IRAM; the C64 loop accesses
    them with 32-bit loads / read-modify-write stores only
    - bus scheme of Vera-Module-RBL-C64: after PHI2 rises poll /IO1 / /IO2 for
    at most IO_QUALIFY_NS, sample A0-A7 and drive the read byte at once
    - banner with size, DRAM / IRAM pages and free memory
    - docs: README, root READMEs, Logs (comparison with RBL-C64)
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2026-11-01 docs: wiring infographics (Atari 130XE, C64), pinouts checked; C64 test prints the value read
    - docs/wiring.py generates wiring_atari.svg and wiring_c64.svg: J3 (from
    the netlist) to the Atari cartridge slot + 130XE ECI and to the C64
    expansion port, with the J3 pin number on each connector pin
    - pinouts checked online: ECI lettered row fixed (A reserved, GND on H);
    the 800XL PBI carries no ~D1XX (decode $D1xx from A8-A15 externally)
    - c64-test: the presence check prints the value read back (stuck data
    bit vs no unit)
    - READMEs link the infographics
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2026-11-01 firmware(6502_monitor): Atari fixed roles, registers in $D1xx, 256-byte RAM window in $D5xx
    - $D1FB-$D1FC count, $D1FD-$D1FE 16-bit bank register, $D1FF PBI select
    latch (bit 7), $D500-$D5FF the current bank
    - the swapped mode, the $D5FF latch, the $D1FF protection and D1FF_RAM
    are gone; the OS PBI scan leaves the device deselected
    - PHI1 decode: 22 instructions for a RAM read
    - Atari test: COUNT, BANK REG, PROTECT, MARCH, LIMIT, KEEP; py65 model
    with 11 faults, all detected
    - docs: READMEs, HARDWARE, PIN-MAPPING (md, tex, pdf), Logs
2026-11-01 firmware(6502_monitor): GEODISK.SYS, D9: RAM disk for MyDOS on the paged RAM
    - resident SIO handler (423 bytes) relocated to MEMLO, page aligned;
    relocation table from two builds ($2000 / $2100) by mkgeodisk.py
    - installer: finds the device, copies the OS ROM to the RAM under it,
    switches the ROM off and points SIOV at the handler; DOSINI hook for RESET
    - D9: one 256-byte sector per bank; R / W / P, S, PERCOM, format
    - test_geodisk.py: py65 with a fake OS and the device model, 31 checks at
    three load addresses
2026-11-01 firmware(sidboard): 6502_monitor bus loop, sid-cctl and sid-pbi builds
    - sid-cctl: SID at $D500-$D51E on ~CCTL (J3 12), always on, no latch
    - sid-pbi: SID at $D100-$D11E on ~D1XX (J3 11), PBI device ID $80,
    select latch $D1FF; deselect keeps the voices playing
    - sid-demo: sid-cctl plus the built-in tune
    - bus loop from 6502_monitor: Core 1 with interrupts masked, PHI1 decode
    in assembly, drive at the PHI2 rise, write sampled 120 ns after it,
    lock-free log ring, LogTask the only Serial writer, SidTask on Core 0
    - pins as the board netlist (A0-A7, CCTL moved to GPIO23); efuse check
    and no RTS / DTR on the monitor; SID register names fixed
    - docs: README, PIN_MAPPING, Logs
2026-11-01 docs(sidboard): DAC1 audio wiring drawing, GPIO25 isolated from the TXS0108E; low-pass corner fixed (160 Hz)
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2026-11-02 schematic: J3 symbol replaced by the 2x16 Odd_Even one, matching the footprint pad numbering
    Same footprint (PinHeader_2x16_P2.54mm_Vertical_SMD), LCSC C6332241 and
    timestamp; wires and labels reassigned pin by pin, netlist unchanged.
    J3 value updated on the PCB, in the .net and in the BOM csv.
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2026-11-02 output_job.sh: XML netlist made by kicadcli (installed into ~/bin if missing); v1.2 outputs regenerated
    utilities/kicadcli: command line tool for the KiCad 5 schematic (list,
    netlist, pins, erc, export-xml) and board (pads, check, gerbers, drill).
    output_job.sh installs it into $HOME/bin when it is not in the PATH,
    adds $HOME/bin to the PATH, writes ESP32-BOBOARD-5V.xml with it (no more
    'Generate BOM' in eeschema) and the grouped BOM with bom2grouped_csv.xsl.
    Regenerated for v1.2: JLCPCB BOM (J3 Odd_Even symbol, same LCSC), CPL,
    schematic PDF. STEP/VRML and the zip kept: the flatpak kicad-cli cannot
    see /usr/share/kicad, so the 3D models were missing.
2026-11-02 output_job.sh: STEP made by kicad2step (KiCad 5), board recoloured to the solder mask green
    kicad2step runs outside the flatpak, so it finds the KiCad 5 3D models in
    /usr/share/kicad and the RetroBitLab ones (the flatpak kicad-cli left all of
    them out). Its board green (69,170,69) is changed to 80,124,105 as in the
    previous export; kicad-cli stays as fallback when kicad2step is missing.
    images/ESP32-BOBOARD-5V.step regenerated (checked in FreeCAD: valid shape).
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2026-11-02 README: 3D links to images/ (output_job.sh outputs), 3D Viewer on master; old 3D/ STEP and WRL removed
    The 3D Viewer link pointed to the main branch, which does not exist (404).
    3D/ESP32-BOBOARD-5V.step and .wrl (September 2025, old J3) were no longer
    linked; 3D/ keeps the rendered PNGs.
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
